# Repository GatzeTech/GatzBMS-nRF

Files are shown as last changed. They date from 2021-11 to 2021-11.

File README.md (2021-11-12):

# GatzBMS-nRF

Short explanation for now.

I was a bit annoyed with the Chinese BMS's that you don't have any feedback on the status of for example balancing or why it cutt off power. Once I was in the middle of nowhere when my eBike suddenly stopped and physically I'm really dependant on the electric system so for example in such case, I want to read out the voltage's and decide for myself if it is still safe to go on. If I have to bike myself physically longer distance's (5 km) I can be sick for day's. In that case one cell group was a little bit off, but still in the safe range, in that case I want to be able to put the mosfets on again for example via bluetooth.

So I came up with the idea to design myself a BMS. The goal is to use simple components (also with the chip delivery problems in mind) except for the microcontroller/Soc. It's a compromise between functionality, costs, availability, simplicity.

Design choice's I will discuss later.

At the moment I'm busy with the software.

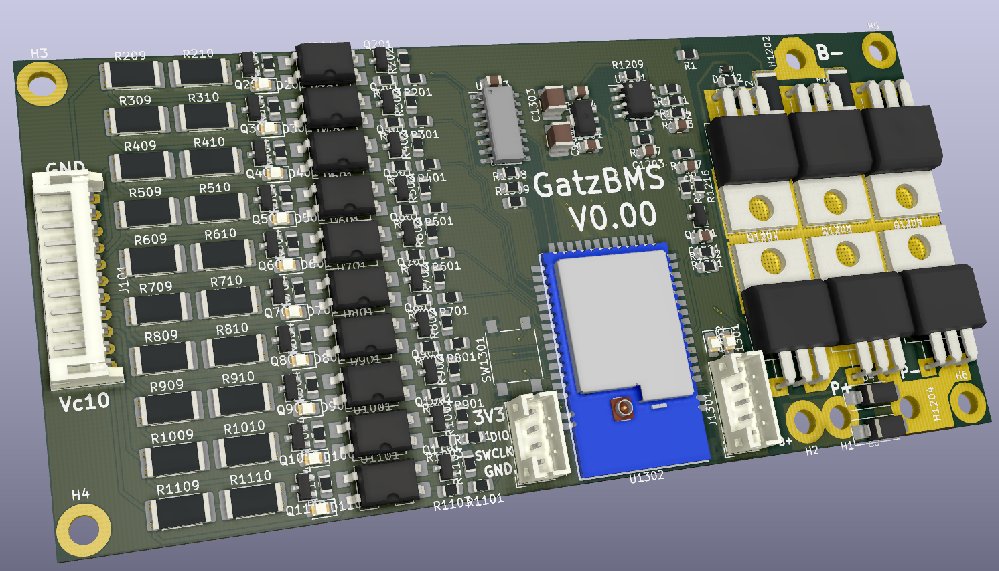
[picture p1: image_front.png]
This is an image


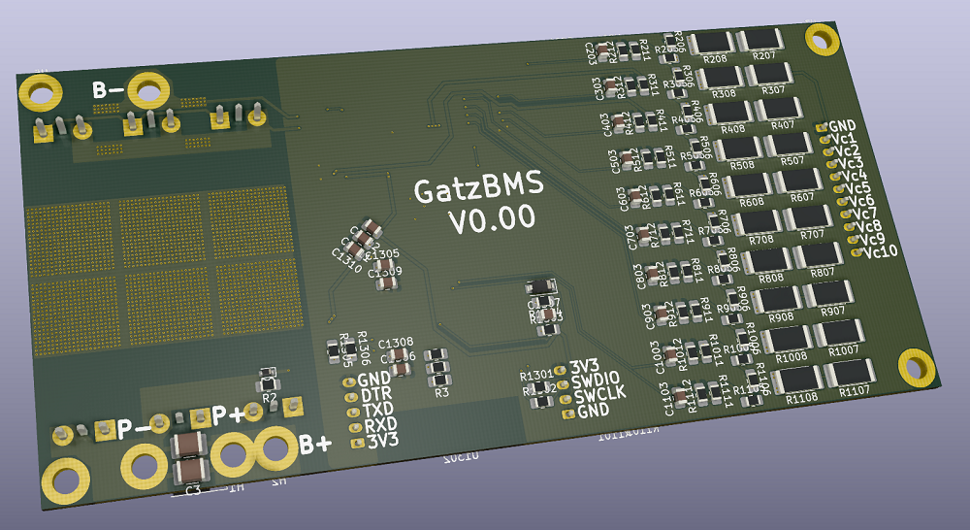
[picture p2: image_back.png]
This is an image


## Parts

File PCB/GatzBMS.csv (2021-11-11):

Reference | Quantity | Value | Footprint | Datasheet | Supplier 2 | Supplier 2 Part Number | Supplier 1 | Supplier 1 Part Number | Supplier 5 | Supplier 5 Part Number
C1 C1201 | 2 | 1N | Capacitor_SMD:C_0805_2012Metric_Pad1.18x1.45mm_HandSolder | ~
C1202 C1203 C1301 C1304 C1305 C1306 C1307 C1308 C1309 C1310 C1311 C1312 C1313 | 13 | 100N | Capacitor_SMD:C_0805_2012Metric | ~
C1302 C1303 | 2 | 4.7u | Capacitor_SMD:C_1210_3225Metric_Pad1.33x2.70mm_HandSolder | ~ | Reichelt | KEM X7R1210 4,7U
C2 C3 | 2 | 1.5u | Capacitor_SMD:C_1210_3225Metric_Pad1.33x2.70mm_HandSolder | ~ | Reichelt | ECC KTS101B155K1
C203 C303 C403 C503 C603 C703 C803 C903 C1003 C1103 | 10 | 1N | Capacitor_SMD:C_0805_2012Metric | ~
D1 | 1 | 1N4148W | Diode_SMD:D_SOD-123 | https://www.vishay.com/docs/85748/1n4148w.pdf |  |  | Conrad | 1582022
D2 D1202 | 2 | Z1SMA15 | Diode_SMD:D_SOD-523 |  |  |  | Conrad | 556861
D1302 | 1 | Red | LED_SMD:LED_0805_2012Metric_Pad1.15x1.40mm_HandSolder | ~ | Reichelt | RND 135-00184
D201 D301 D401 D501 D601 D701 D801 D901 D1001 D1101 D1301 | 11 | Green | LED_SMD:LED_0805_2012Metric_Pad1.15x1.40mm_HandSolder | ~ | Reichelt | OSO LGR971
D3 D4 | 2 | D | Diode_SMD:D_SMA_Handsoldering | ~ | Reichelt | M2 DIO
H1 H2 H3 H4 H5 H6 H1202 H1204 | 8 | MountingHole_Pad | MountingHole:MountingHole_3.2mm_M3_ISO7380_Pad_TopBottom | ~
J101 | 1 | Conn_01x11 | Connector_JST:JST_PH_S11B-PH-K_1x11_P2.00mm_Horizontal | ~
J1301 | 1 | Conn_01x05 | Connector_JST:JST_PH_B5B-PH-K_1x05_P2.00mm_Vertical | ~ |  |  | Conrad | 741246
J1302 | 1 | Conn_01x04 | Connector_JST:JST_PH_B4B-PH-K_1x04_P2.00mm_Vertical | ~ |  |  | Conrad | 741223
Q1204 Q1205 Q1206 Q1207 Q1208 Q1209 | 6 | IRFB4410ZPBF | GatzeLib:TO-220-3_Horizontal_TabDown_modified |  |  |  | Conrad | 160946
Q201 Q301 Q401 Q501 Q601 Q701 Q801 Q901 Q1001 Q1101 Q1201 | 11 | BC847 | Package_TO_SOT_SMD:SOT-23 | http://www.infineon.com/dgdl/Infineon-BC847SERIES_BC848SERIES_BC849SERIES_BC850SERIES-DS-v01_01-en.pdf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 |  |  | Conrad | 153157
Q202 Q302 Q402 Q502 Q602 Q702 Q802 Q902 Q1002 Q1102 | 10 | IRLML6244TRPBF | Package_TO_SOT_SMD:SOT-23 |  |  |  | Conrad | 161189
R1 R1307 R1308 R1309 | 4 | 330 | Resistor_SMD:R_0805_2012Metric_Pad1.20x1.40mm_HandSolder | ~
R1201 R1209 R1211 R1303 | 4 | 10K | Resistor_SMD:R_0805_2012Metric_Pad1.20x1.40mm_HandSolder | ~
R1205 R1207 R1208 | 3 | 100K | Resistor_SMD:R_0805_2012Metric_Pad1.20x1.40mm_HandSolder | ~
R1212 R1213 | 2 | 0.005 | Resistor_SMD:R_2512_6332Metric_Pad1.40x3.35mm_HandSolder | ~ |  |  | Conrad | 454322
R3 R4 R5 R1216 R1301 R1302 R1304 | 7 | 100 | Resistor_SMD:R_0805_2012Metric_Pad1.20x1.40mm_HandSolder | ~
R2 R1217 R1218 | 3 | 1M | Resistor_SMD:R_0805_2012Metric_Pad1.20x1.40mm_HandSolder | ~
R202 R302 R402 R502 R602 R702 R802 R902 R1002 R1102 | 10 | 22K | Resistor_SMD:R_0805_2012Metric_Pad1.20x1.40mm_HandSolder | ~
R203 R303 R403 R503 R603 R703 R803 R903 R1003 R1103 | 10 | 620 | Resistor_SMD:R_0805_2012Metric_Pad1.20x1.40mm_HandSolder | ~
R201 R204 R205 R301 R304 R305 R401 R404 R405 R501 R504 R505 R601 R604 R605 R701 R704 R705 R801 R804 R805 R901 R904 R905 R1001 R1004 R1005 R1101 R1104 R1105 R1203 R1204 R1305 R1306 | 34 | 1K | Resistor_SMD:R_0805_2012Metric_Pad1.20x1.40mm_HandSolder | ~
R206 R306 R406 R506 R606 R706 R806 R906 R1006 R1106 R1202 | 11 | 47K | Resistor_SMD:R_0805_2012Metric_Pad1.20x1.40mm_HandSolder | ~
R207 R208 R209 R210 R307 R308 R309 R310 R407 R408 R409 R410 R507 R508 R509 R510 R607 R608 R609 R610 R707 R708 R709 R710 R807 R808 R809 R810 R907 R908 R909 R910 R1007 R1008 R1009 R1010 R1107 R1108 R1109 R1110 | 40 | 10 | Resistor_SMD:R_2512_6332Metric_Pad1.40x3.35mm_HandSolder | ~ |  |  | Conrad | 443148
R211 R311 R411 R511 R611 R711 R811 R911 R1011 R1111 | 10 | 91K | Resistor_SMD:R_0805_2012Metric_Pad1.20x1.40mm_HandSolder | ~
R212 R312 R412 R512 R612 R712 R812 R912 R1012 R1112 | 10 | 6K8 | Resistor_SMD:R_0805_2012Metric_Pad1.20x1.40mm_HandSolder | ~
SW1301 | 1 | SW_Push | Button_Switch_SMD:SW_Push_1P1T_NO_6x6mm_H9.5mm | ~ |  |  |  |  | Aliexpress | 1005001861089000
U1201 | 1 | MCP607 | Package_SO:SOIC-8_3.9x4.9mm_P1.27mm |  | Reichelt | MCP 607-I/SN
U1301 | 1 | MCP1703A-1202_SOT89 | Package_TO_SOT_SMD:SOT-89-3 | http://ww1.microchip.com/downloads/en/DeviceDoc/20005122B.pdf | Reichelt | MCP 1703-3302MB
U1302 | 1 | E73-2G4M04S1B | GatzeLib:E73-2G4M04S1B | http://infocenter.nordicsemi.com/pdf/nRF52832_PS_v1.4.pdf
U1303 | 1 | 74HC4051 | Package_SO:SO-16_3.9x9.9mm_P1.27mm | http://www.ti.com/lit/ds/symlink/cd74hc4051.pdf |  |  | Conrad | 144444
U201 U301 U401 U501 U601 U701 U801 U901 U1001 U1101 | 10 | PC817 | Package_DIP:SMDIP-4_W9.53mm_Clearance8mm | http://www.soselectronic.cz/a_info/resource/d/pc817.pdf |  |  | Conrad | 140234

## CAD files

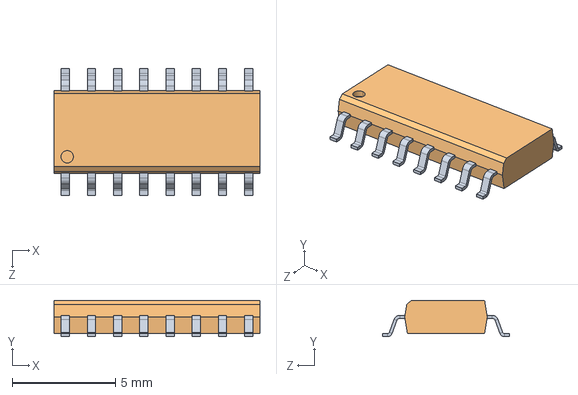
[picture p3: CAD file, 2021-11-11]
PCB/3dshape/SO16.STEP
9.97 x 1.76 x 6.14 mm

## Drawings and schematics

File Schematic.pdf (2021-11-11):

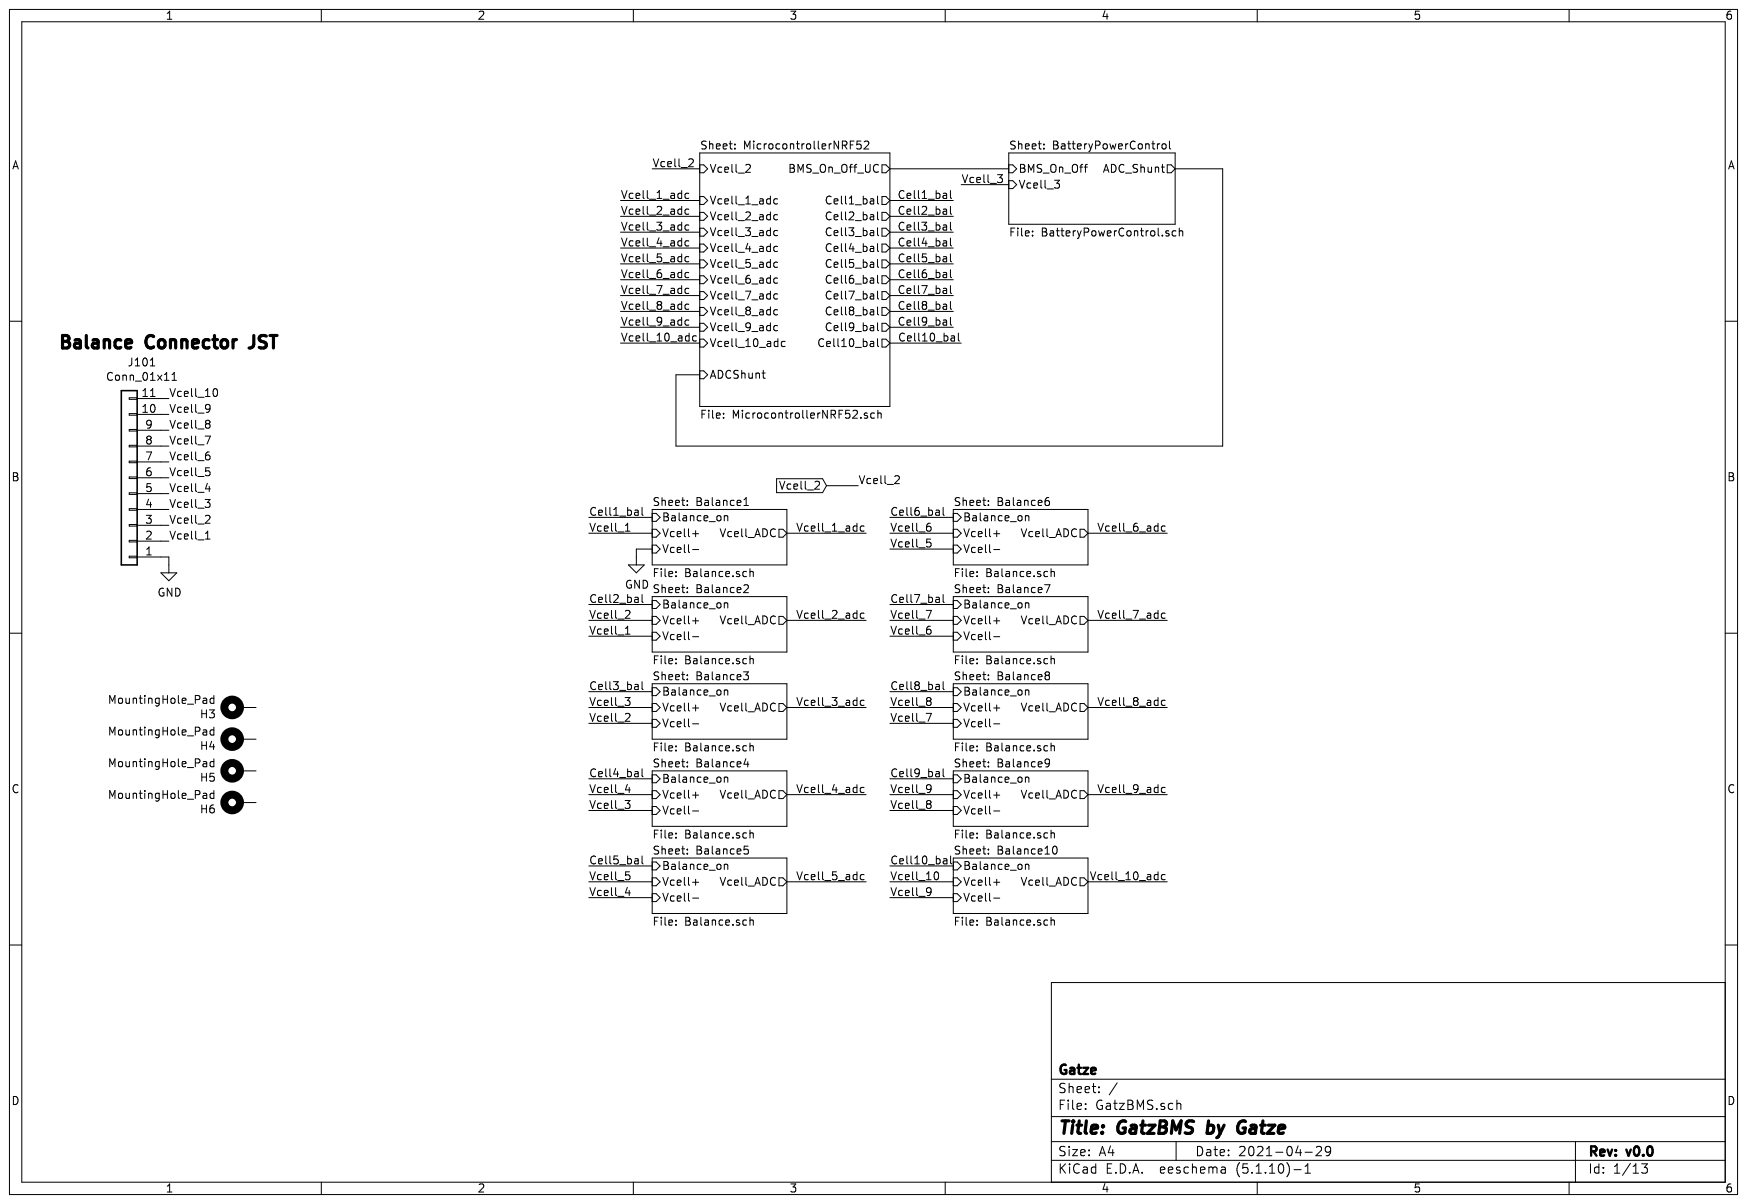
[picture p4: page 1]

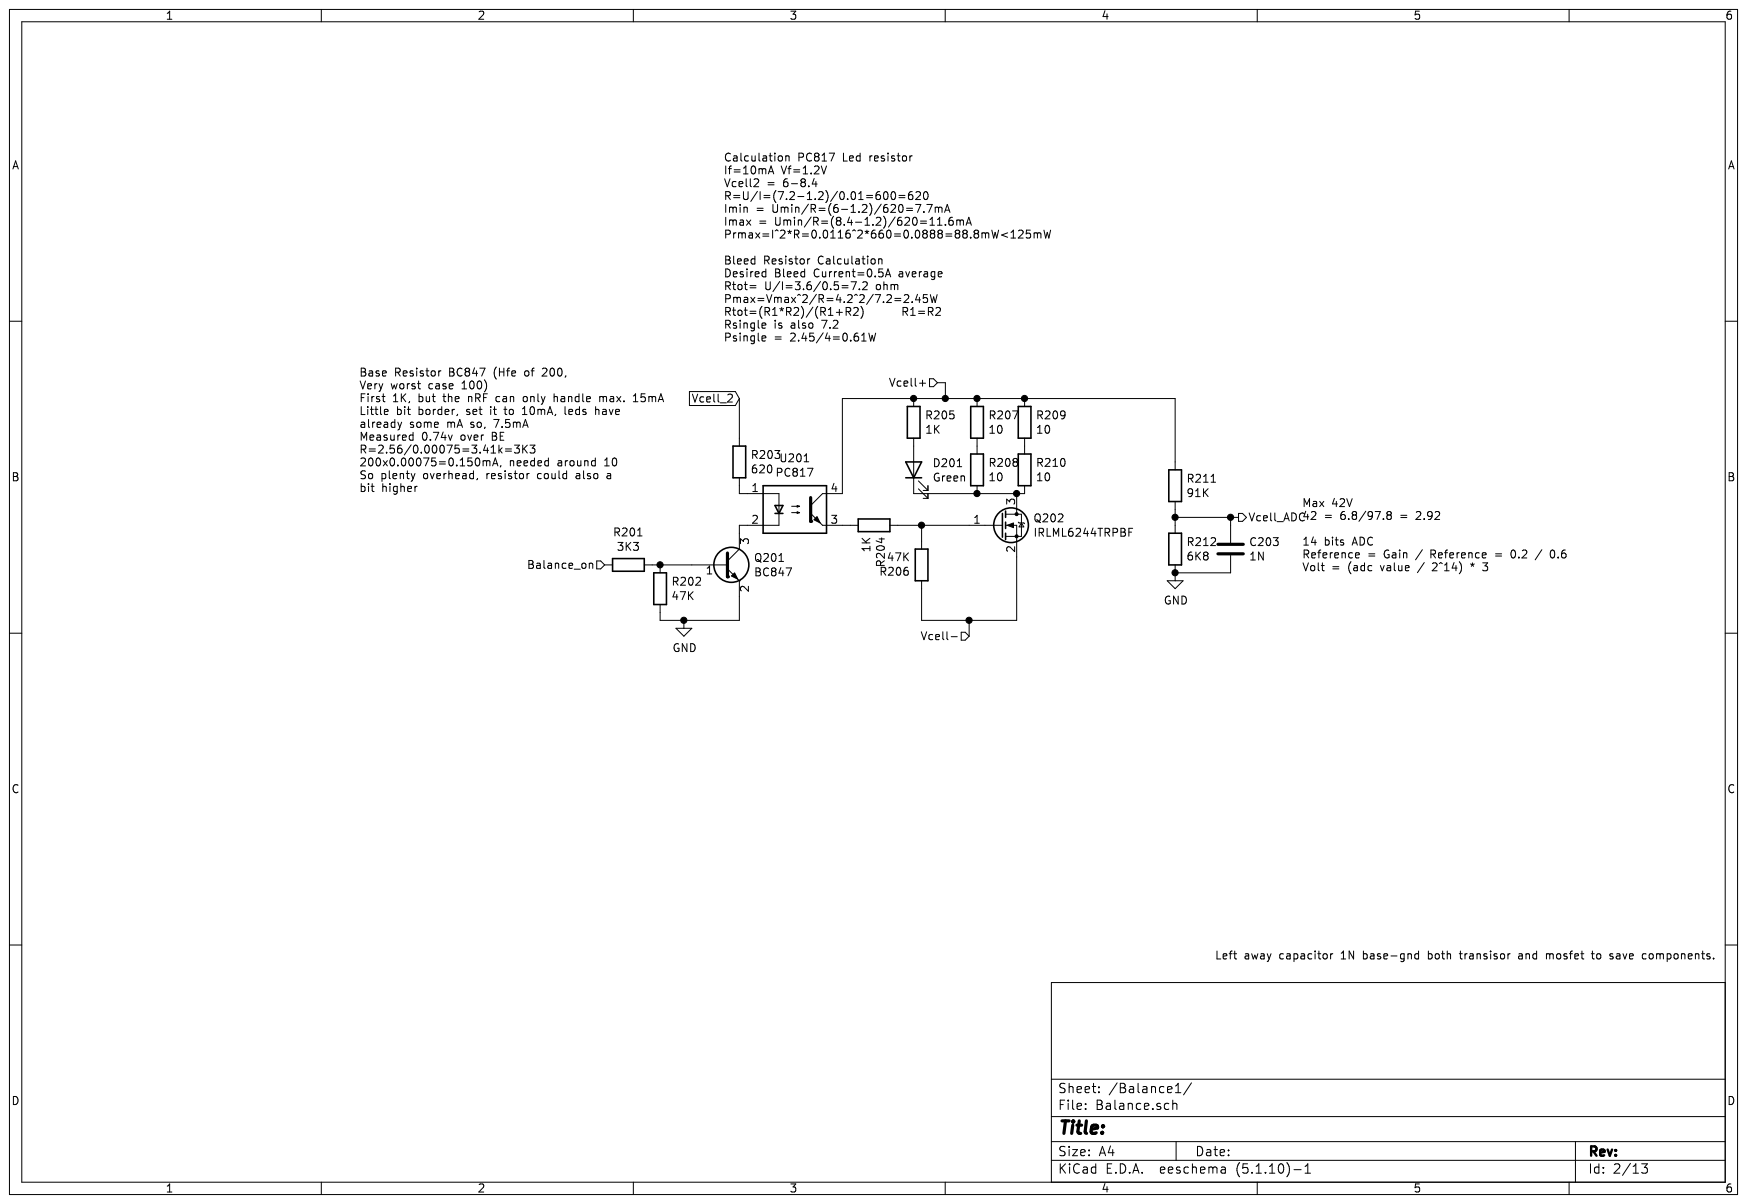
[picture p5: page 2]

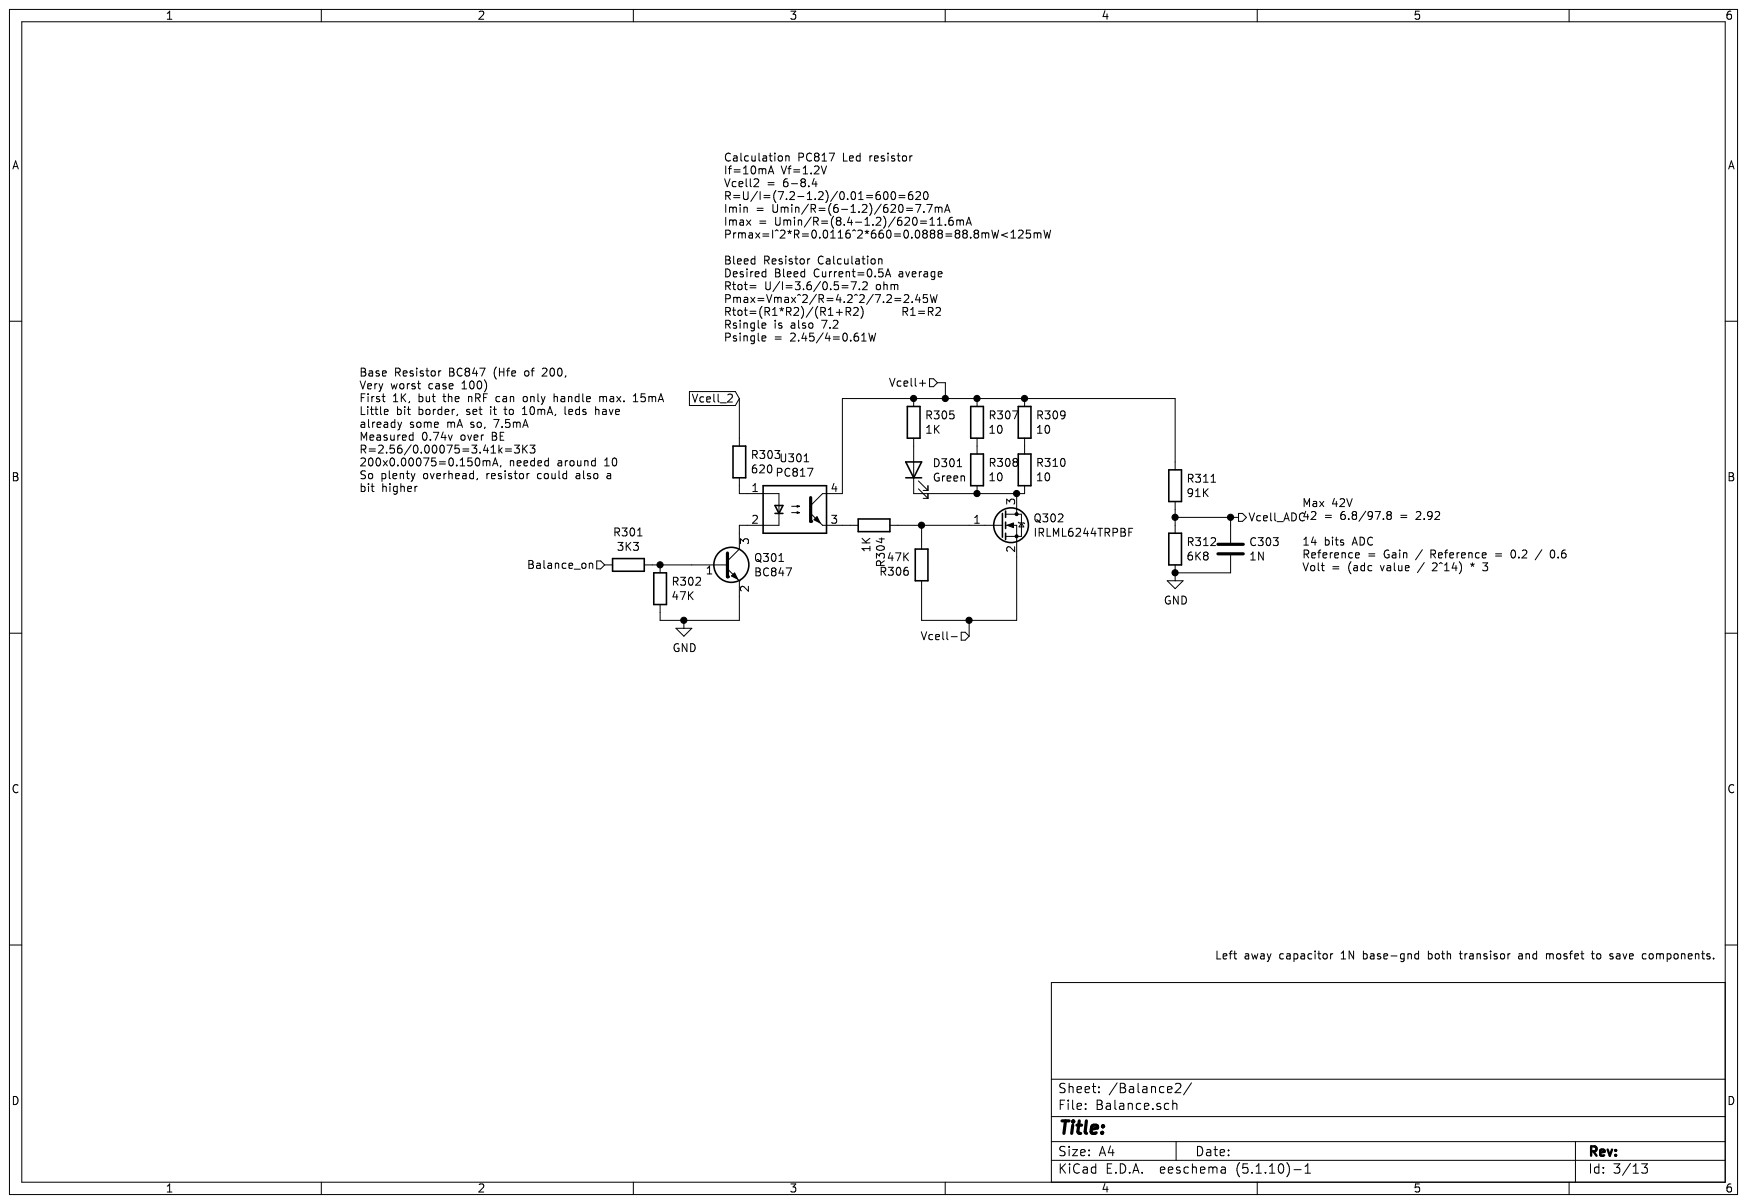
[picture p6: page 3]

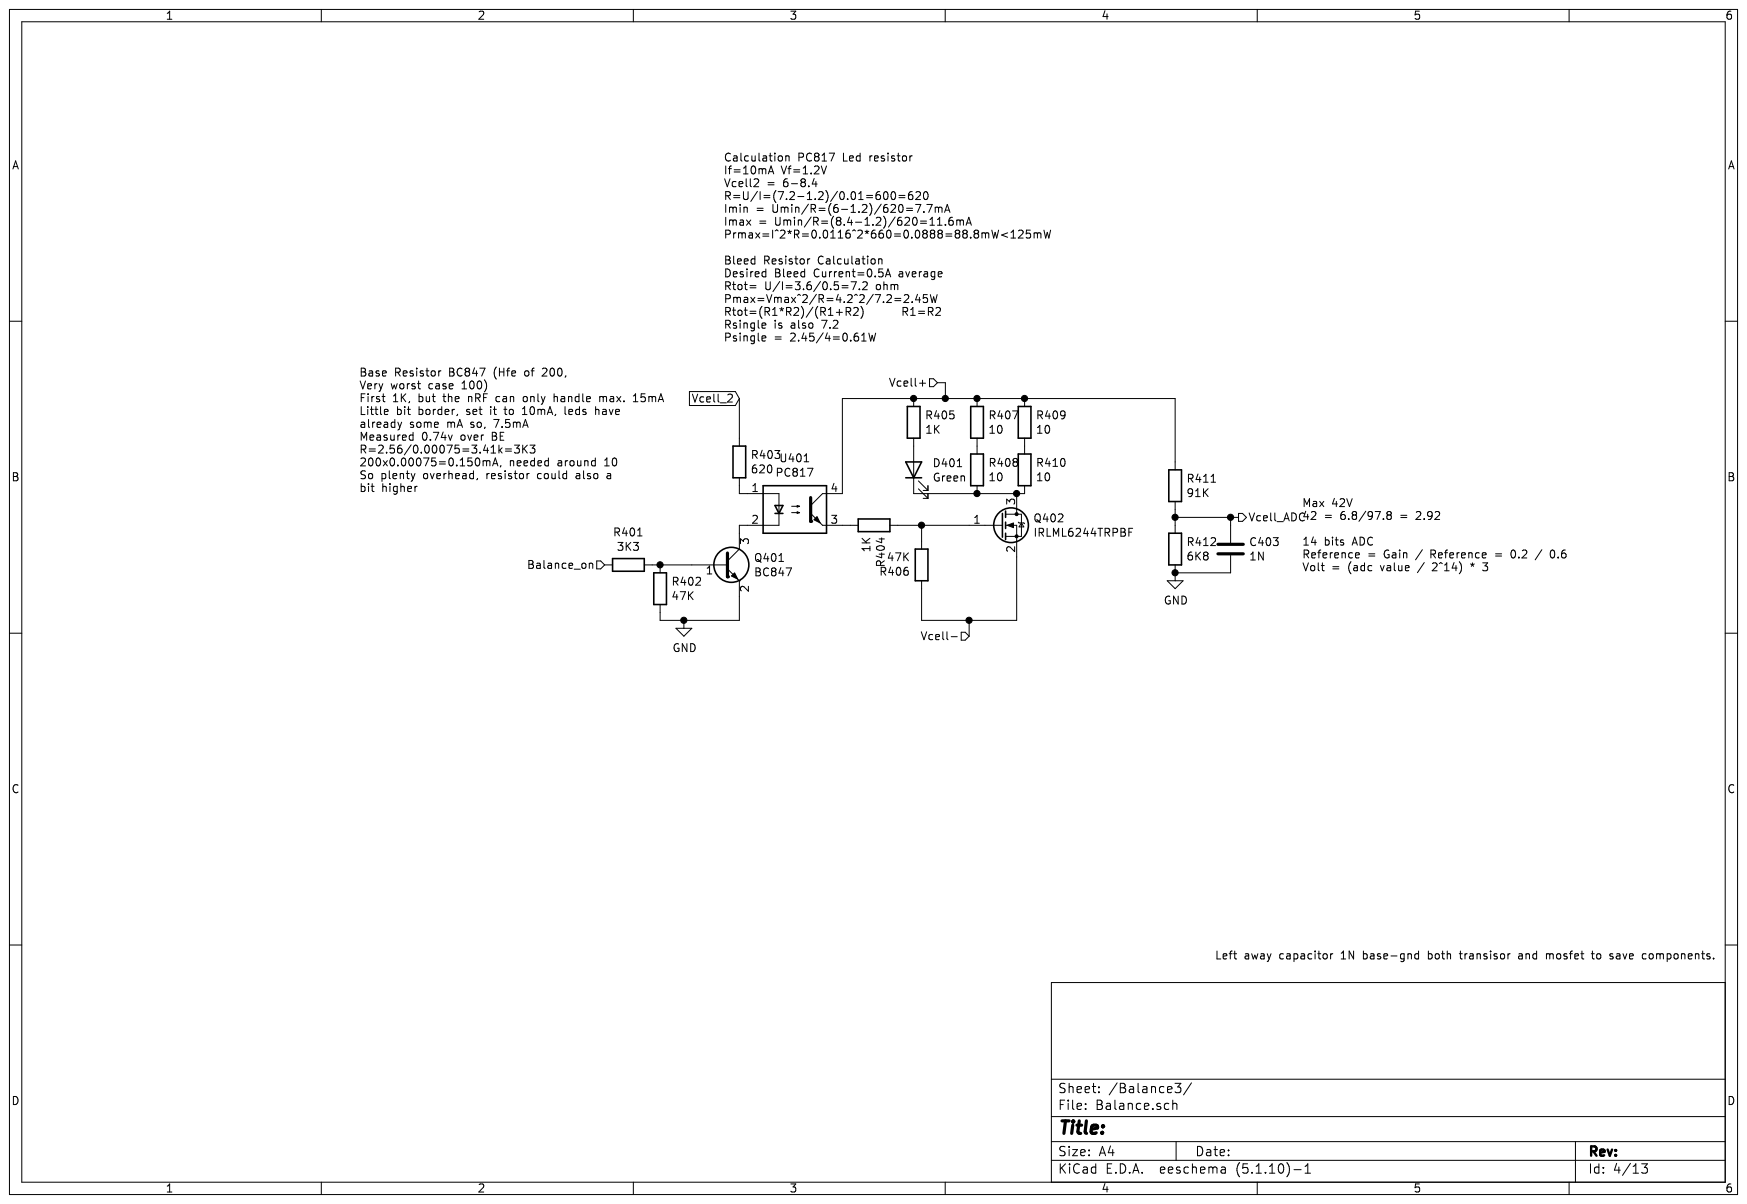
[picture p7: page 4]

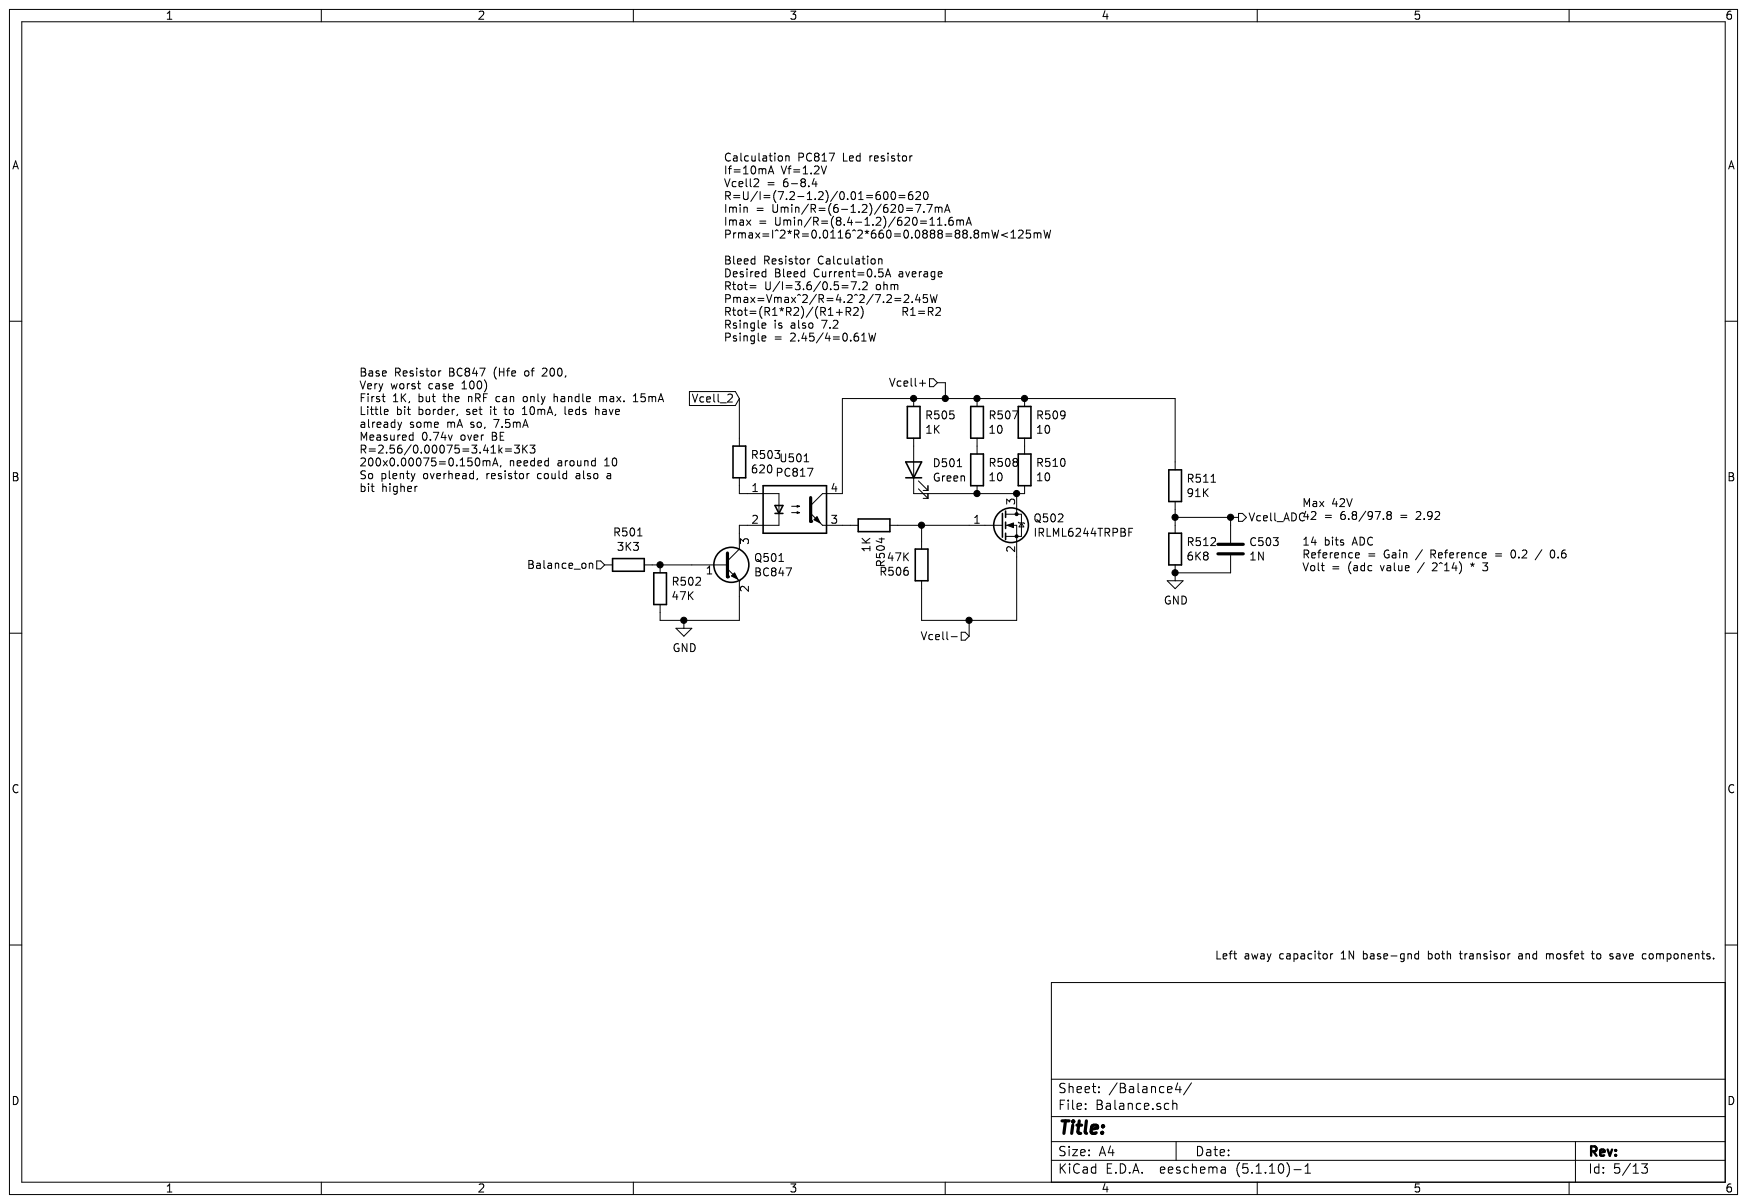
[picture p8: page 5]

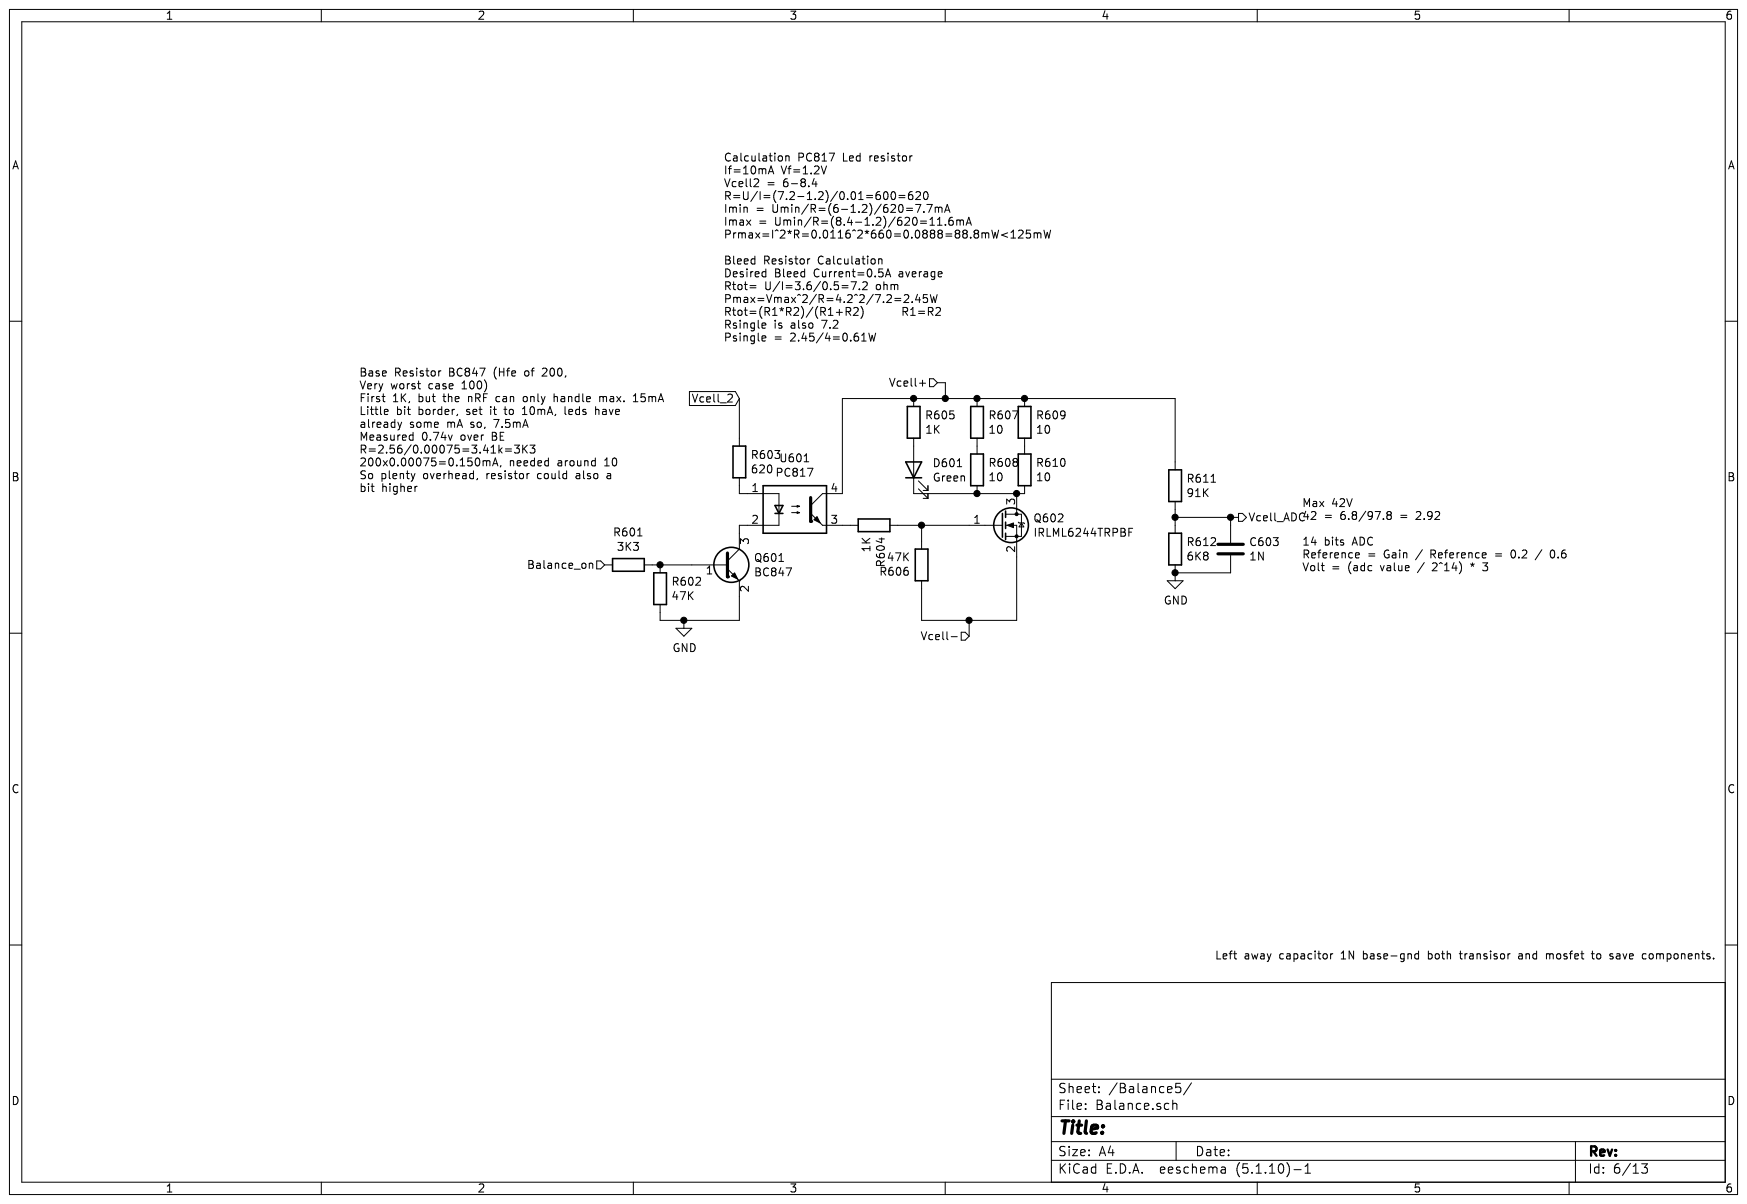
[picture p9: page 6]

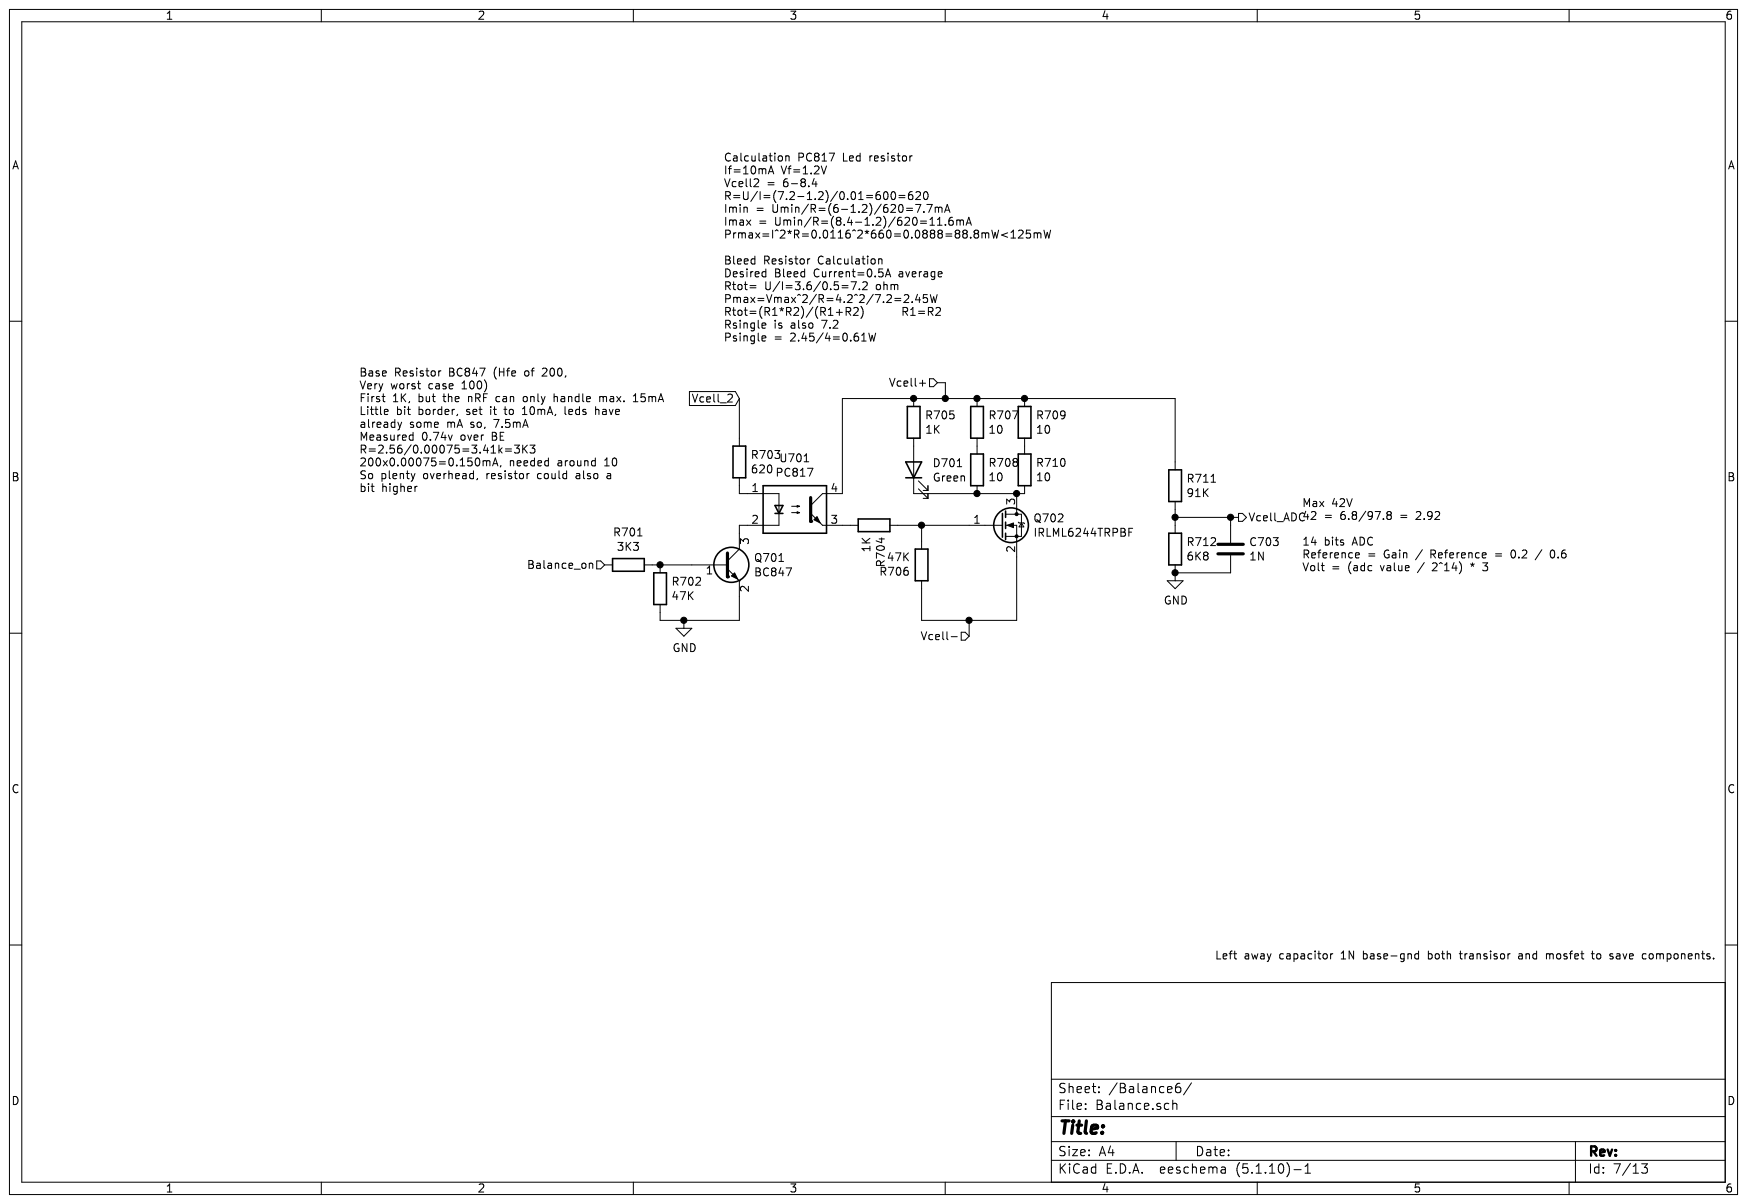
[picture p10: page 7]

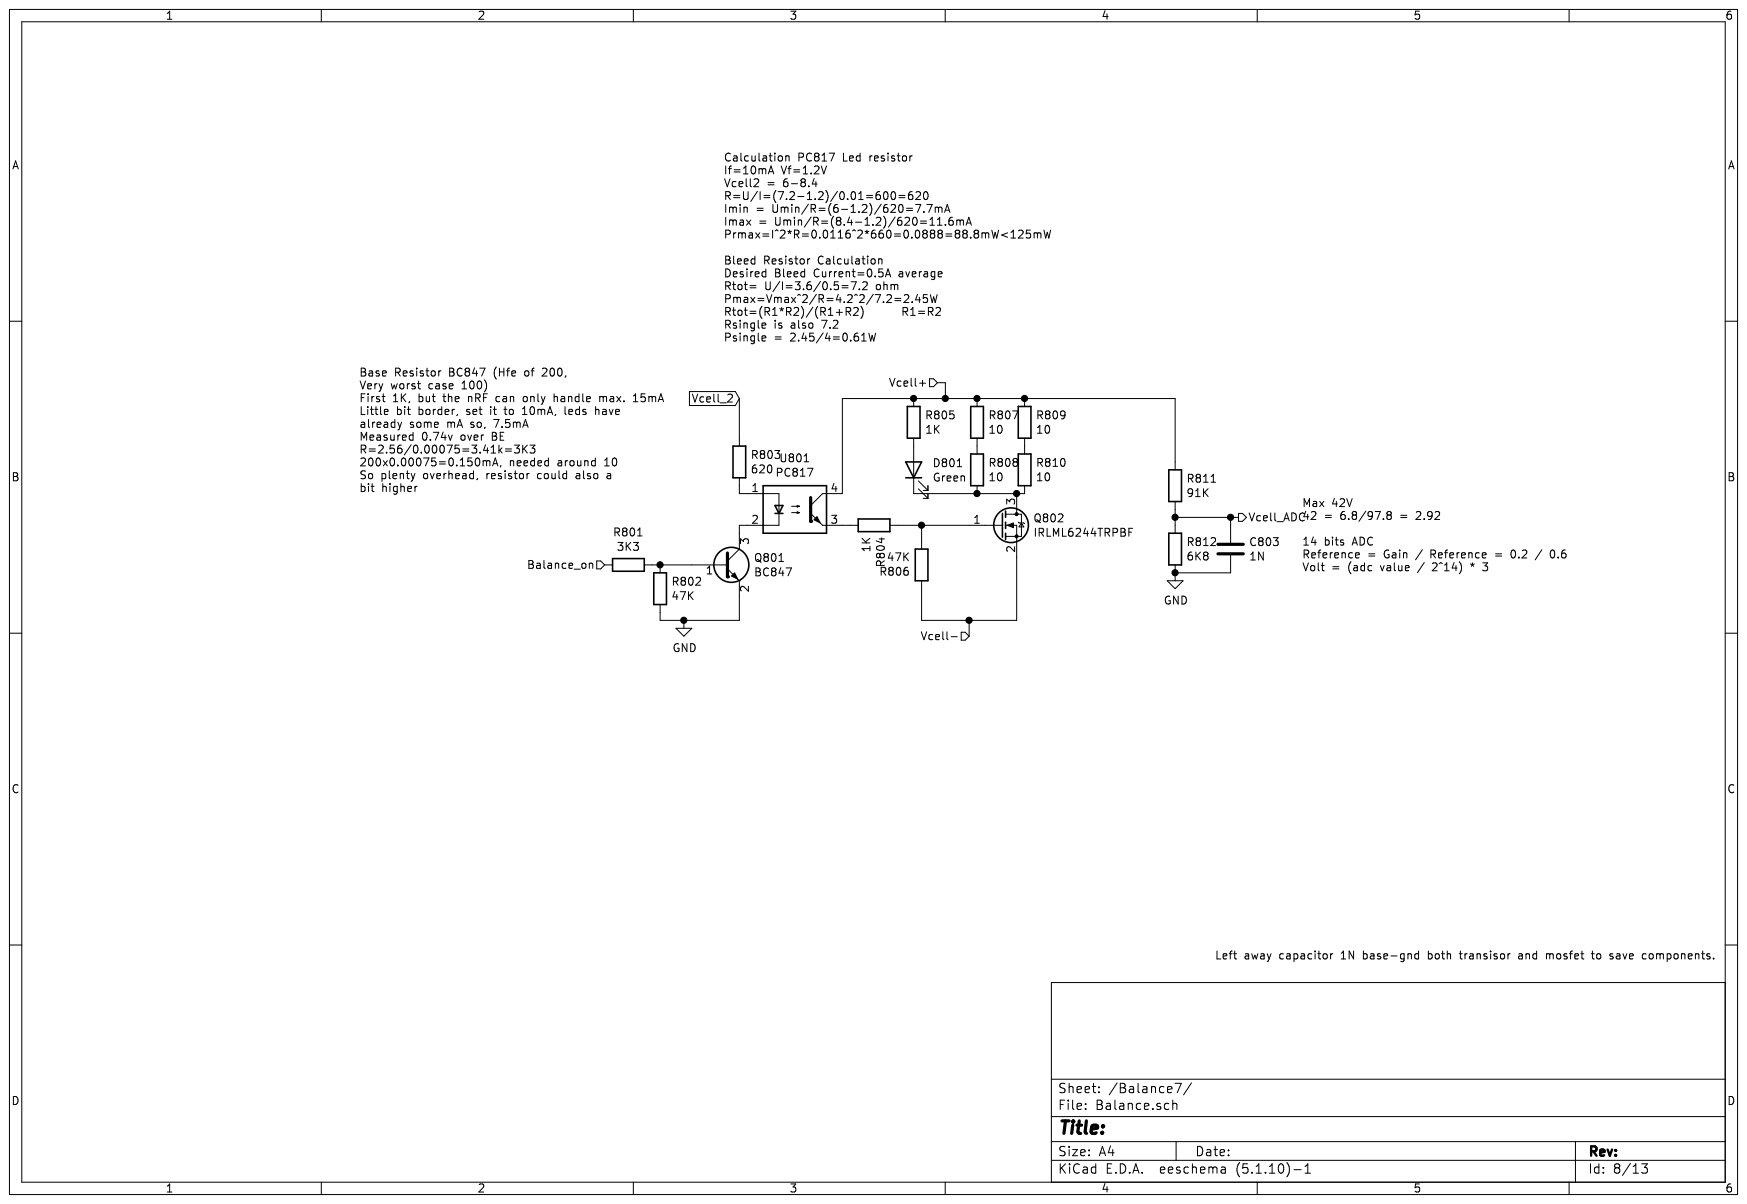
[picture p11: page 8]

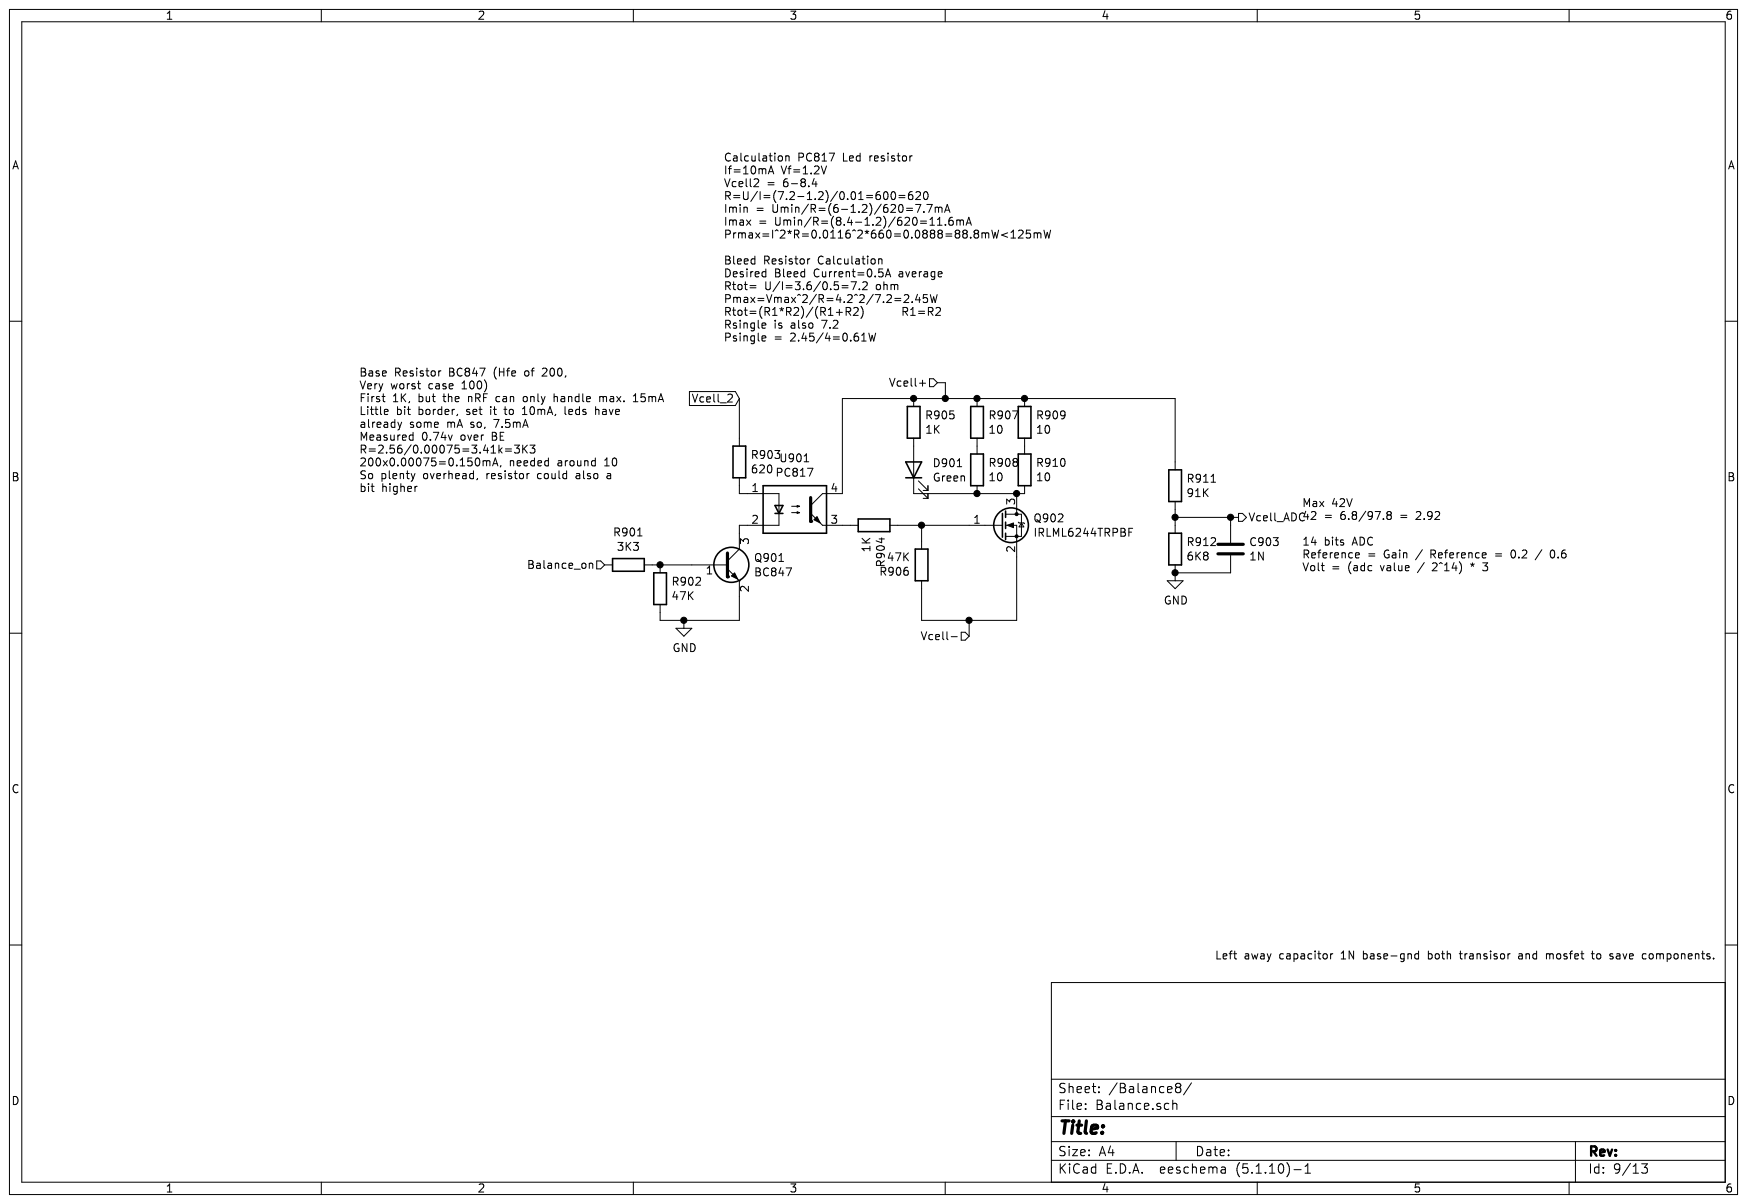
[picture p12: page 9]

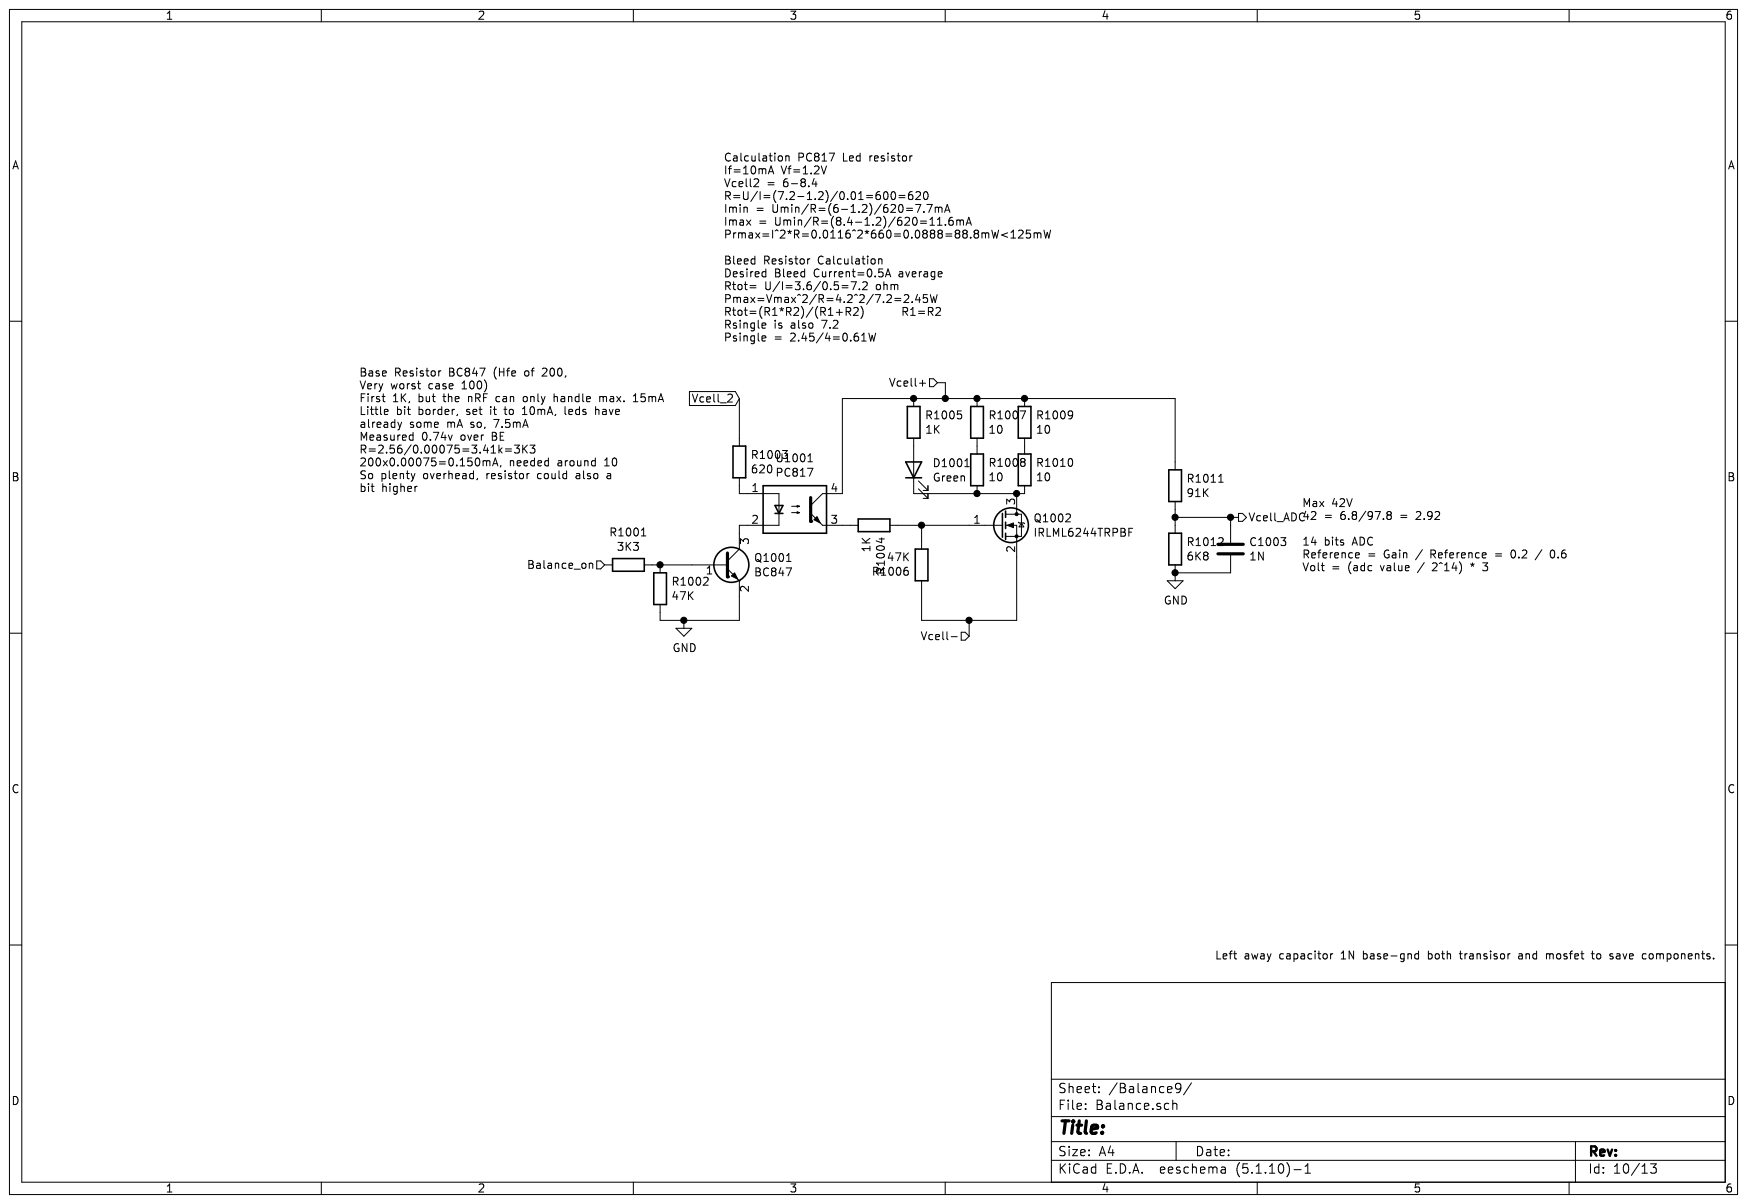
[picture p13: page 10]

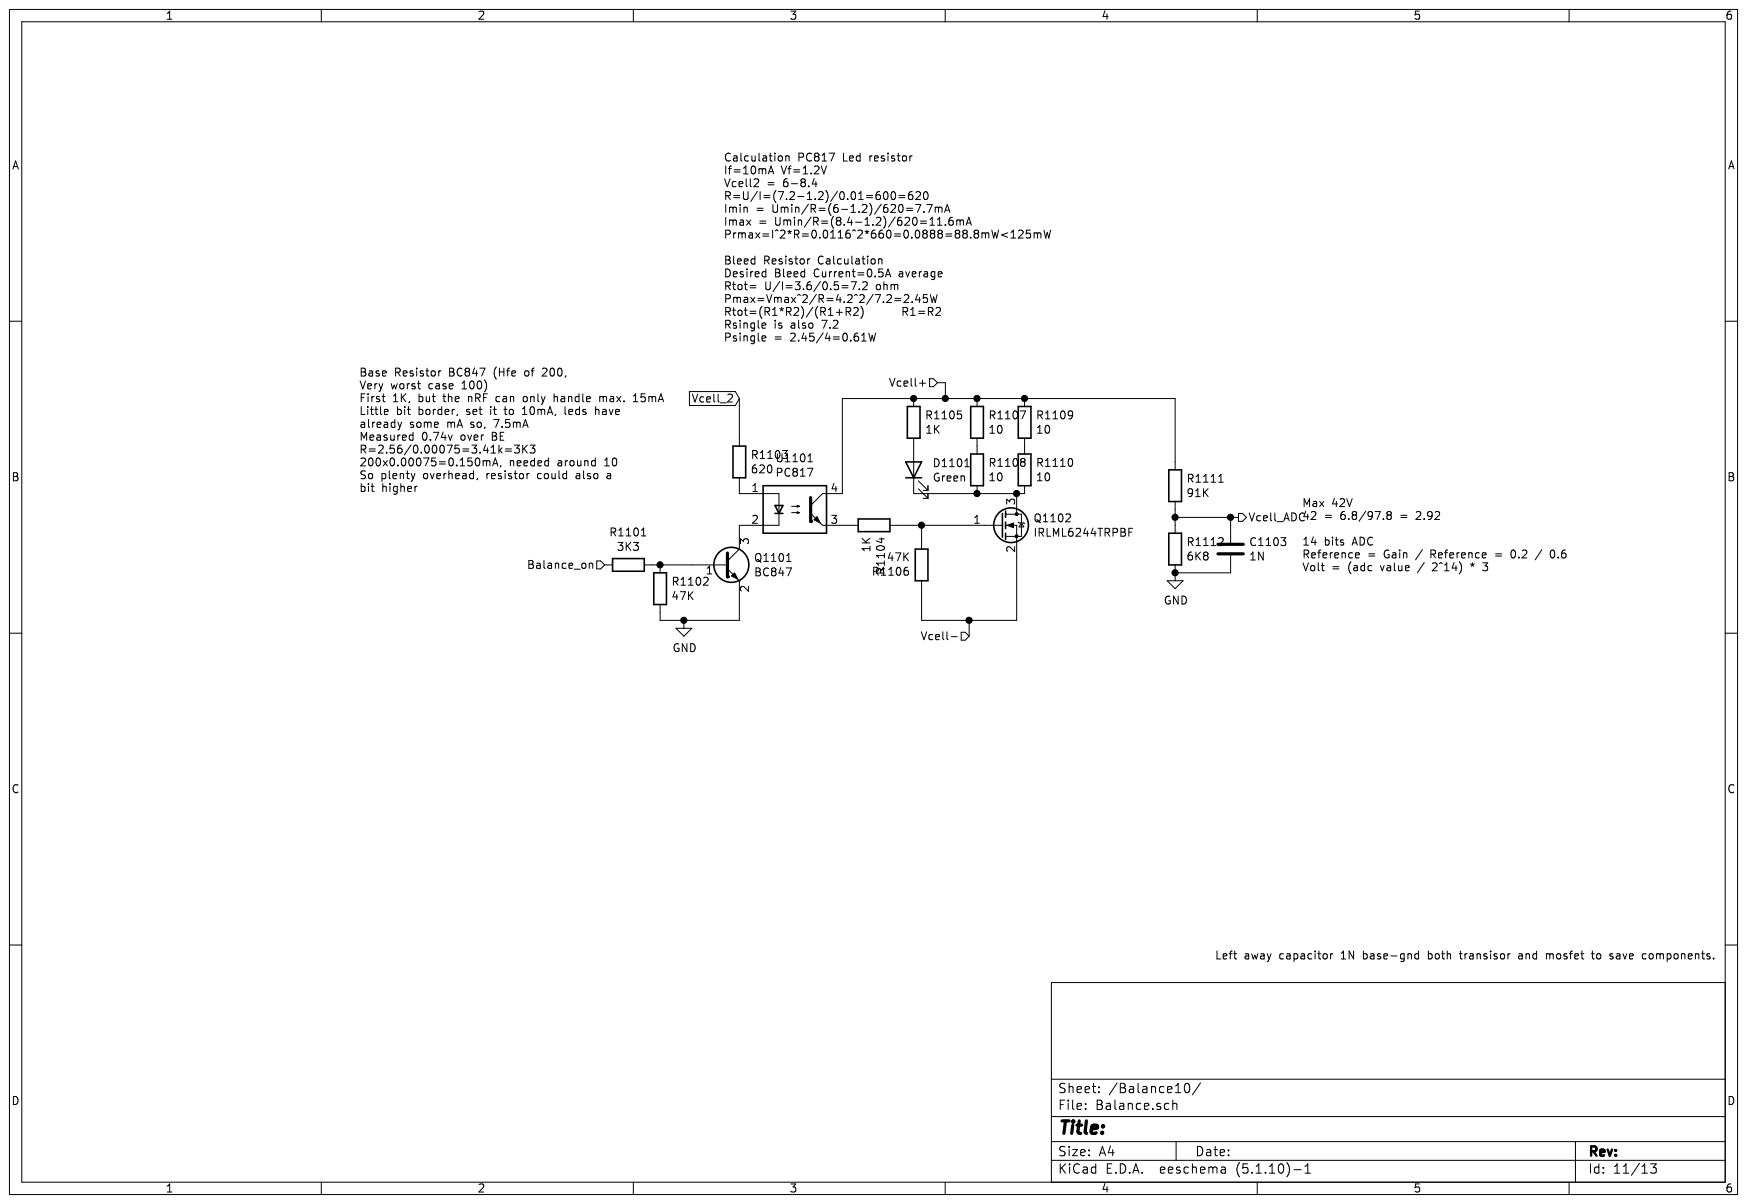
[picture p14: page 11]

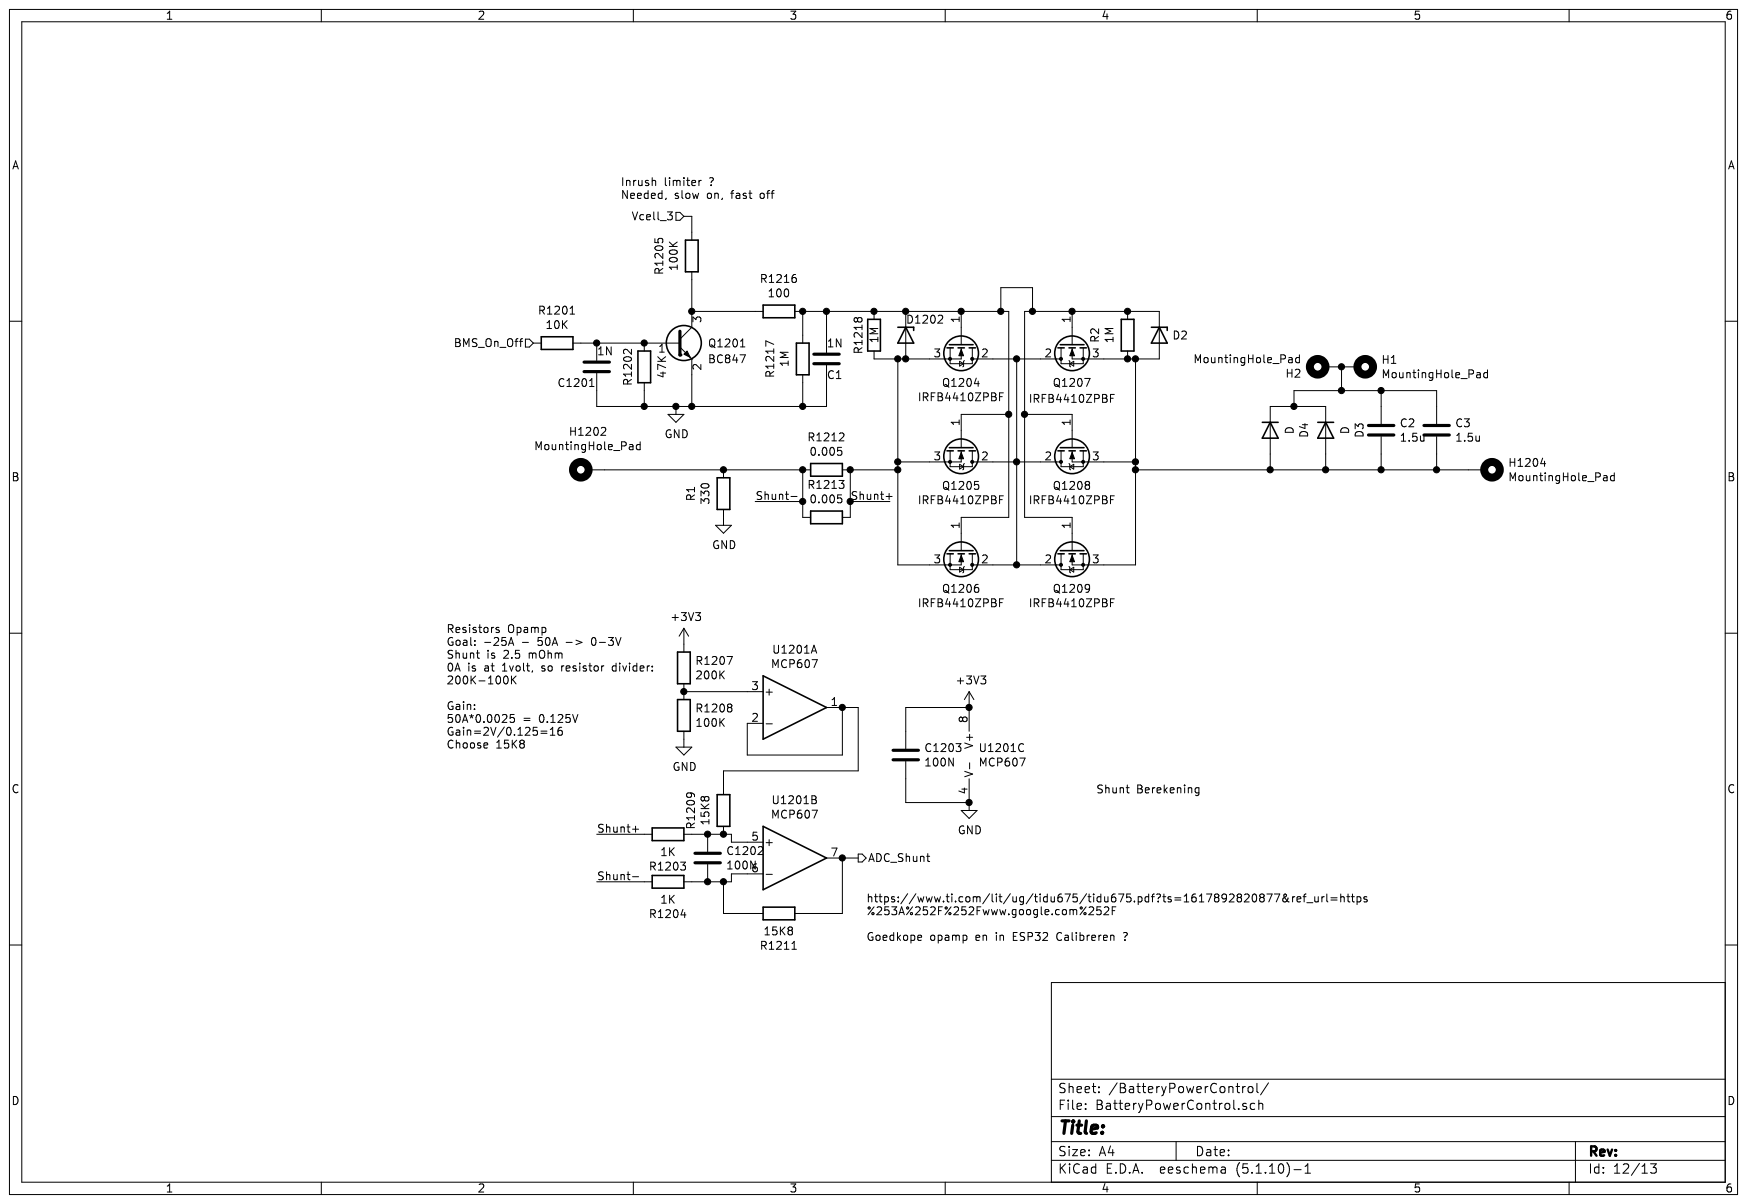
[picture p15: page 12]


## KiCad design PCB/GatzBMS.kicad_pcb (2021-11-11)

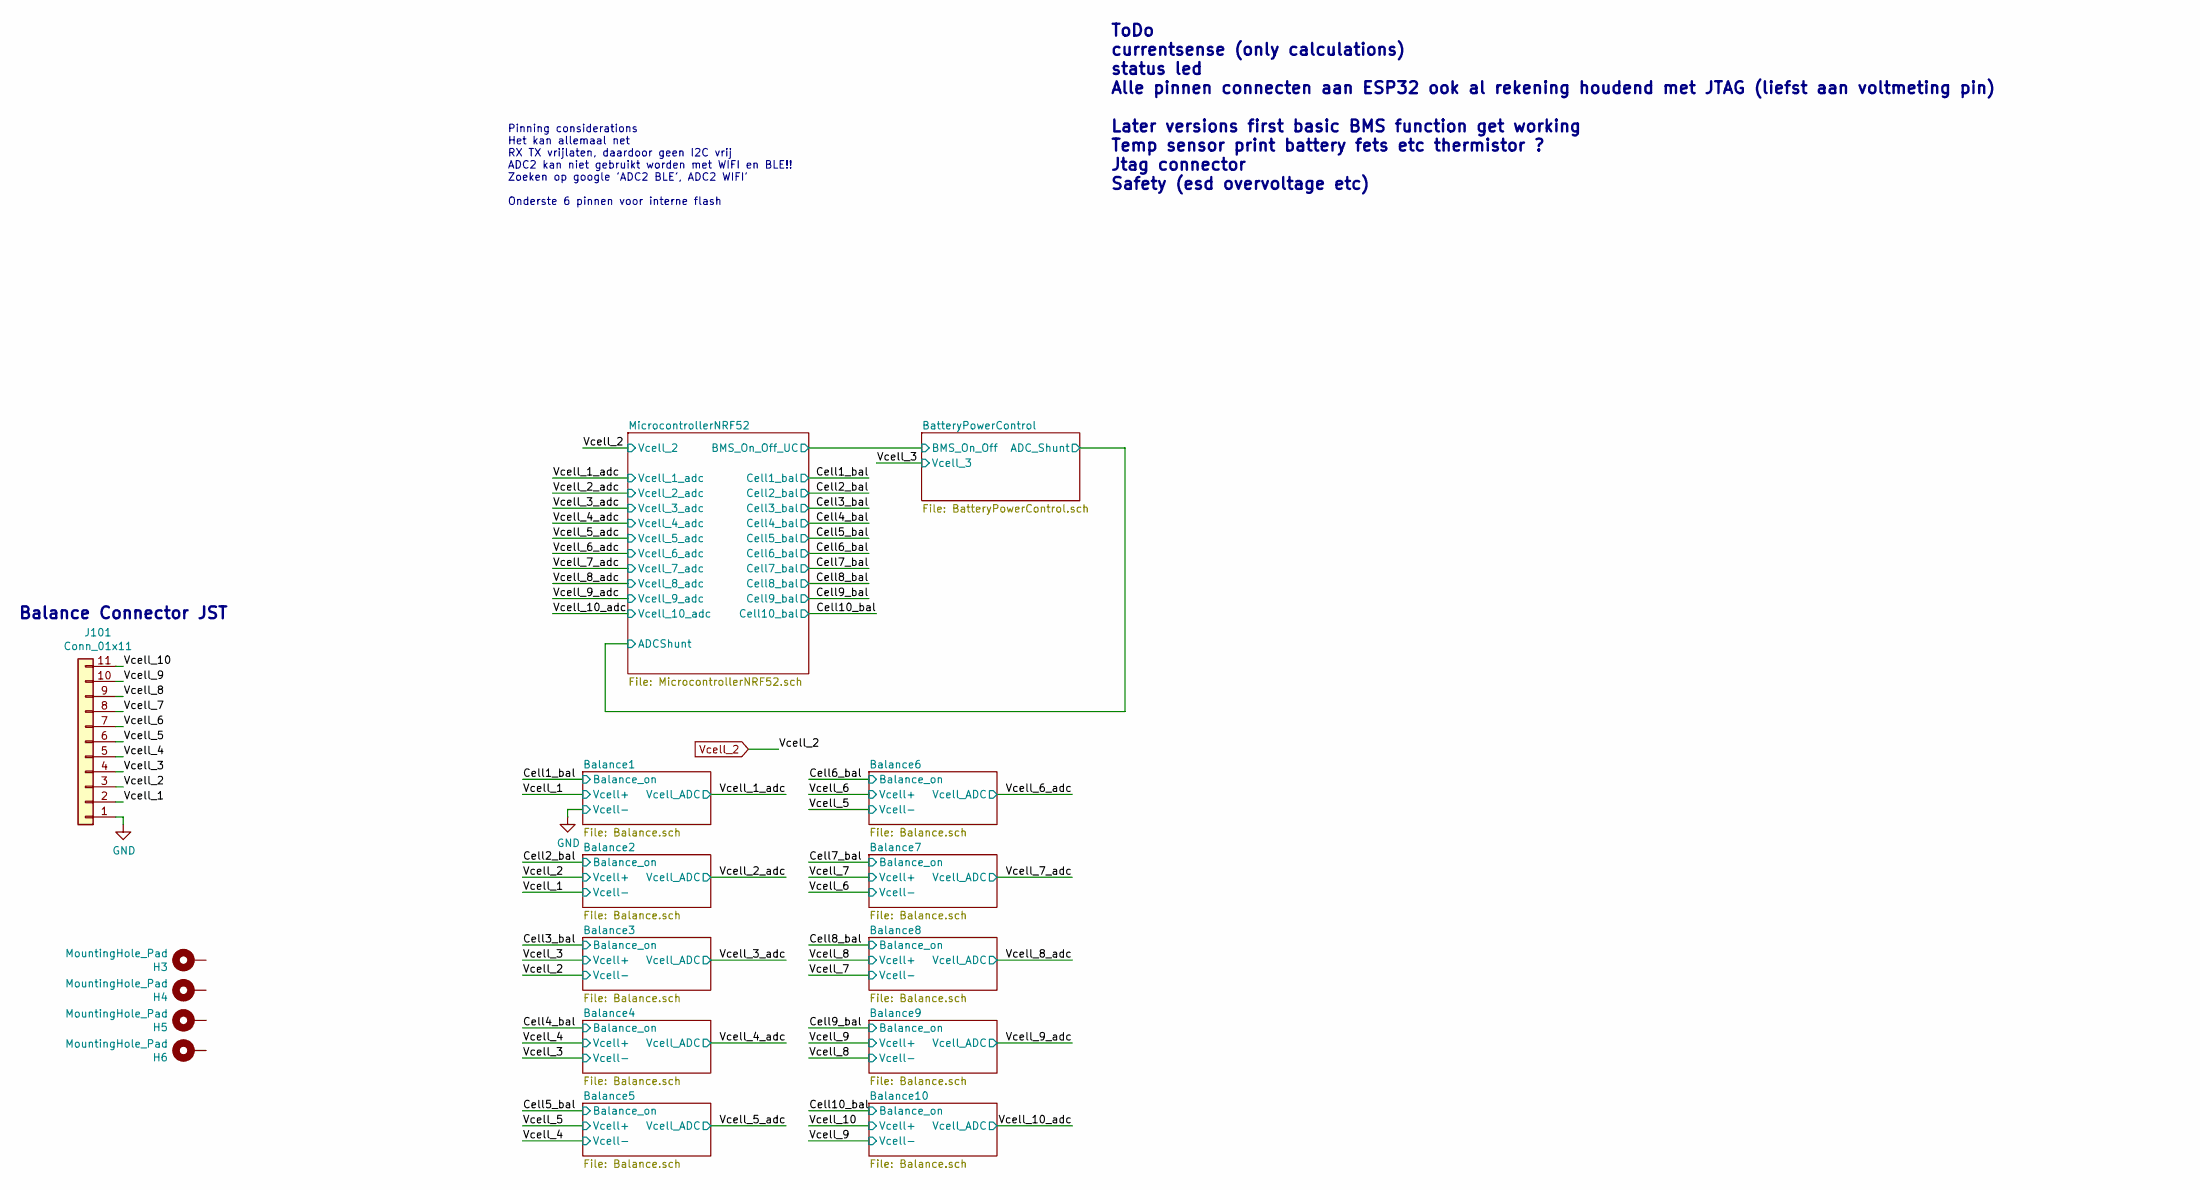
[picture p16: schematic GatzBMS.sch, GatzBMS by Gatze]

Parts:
H3, H4, H5, H6: MountingHole_Pad; MountingHole_3.2mm_M3_ISO7380_Pad_TopBottom
J101: Conn_01x11; JST_PH_S11B-PH-K_1x11_P2.00mm_Horizontal

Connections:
/Vcell_1: J101.2; also elsewhere on the board
/Vcell_3: J101.4; also elsewhere on the board
/Vcell_4: J101.5; also elsewhere on the board
/Vcell_5: J101.6; also elsewhere on the board
/Vcell_6: J101.7; also elsewhere on the board
/Vcell_7: J101.8; also elsewhere on the board
/Vcell_8: J101.9; also elsewhere on the board
/Vcell_9: J101.10; also elsewhere on the board
/Vcell_10: J101.11; also elsewhere on the board
GND: J101.1; also elsewhere on the board
Vcell_2: J101.3; also elsewhere on the board

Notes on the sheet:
Balance Connector JST
ToDo currentsense (only calculations) status led Alle pinnen connecten aan ESP32 ook al rekening houdend met JTAG (liefst aan voltmeting pin) Later versions first basic BMS function get working Temp sensor print battery fets etc thermistor ? Jtag connector Safety (esd overvoltage etc)
Pinning considerations Het kan allemaal net RX TX vrijlaten, daardoor geen I2C vrij ADC2 kan niet gebruikt worden met WIFI en BLE!! Zoeken op google 'ADC2 BLE', ADC2 WIFI' Onderste 6 pinnen voor interne flash

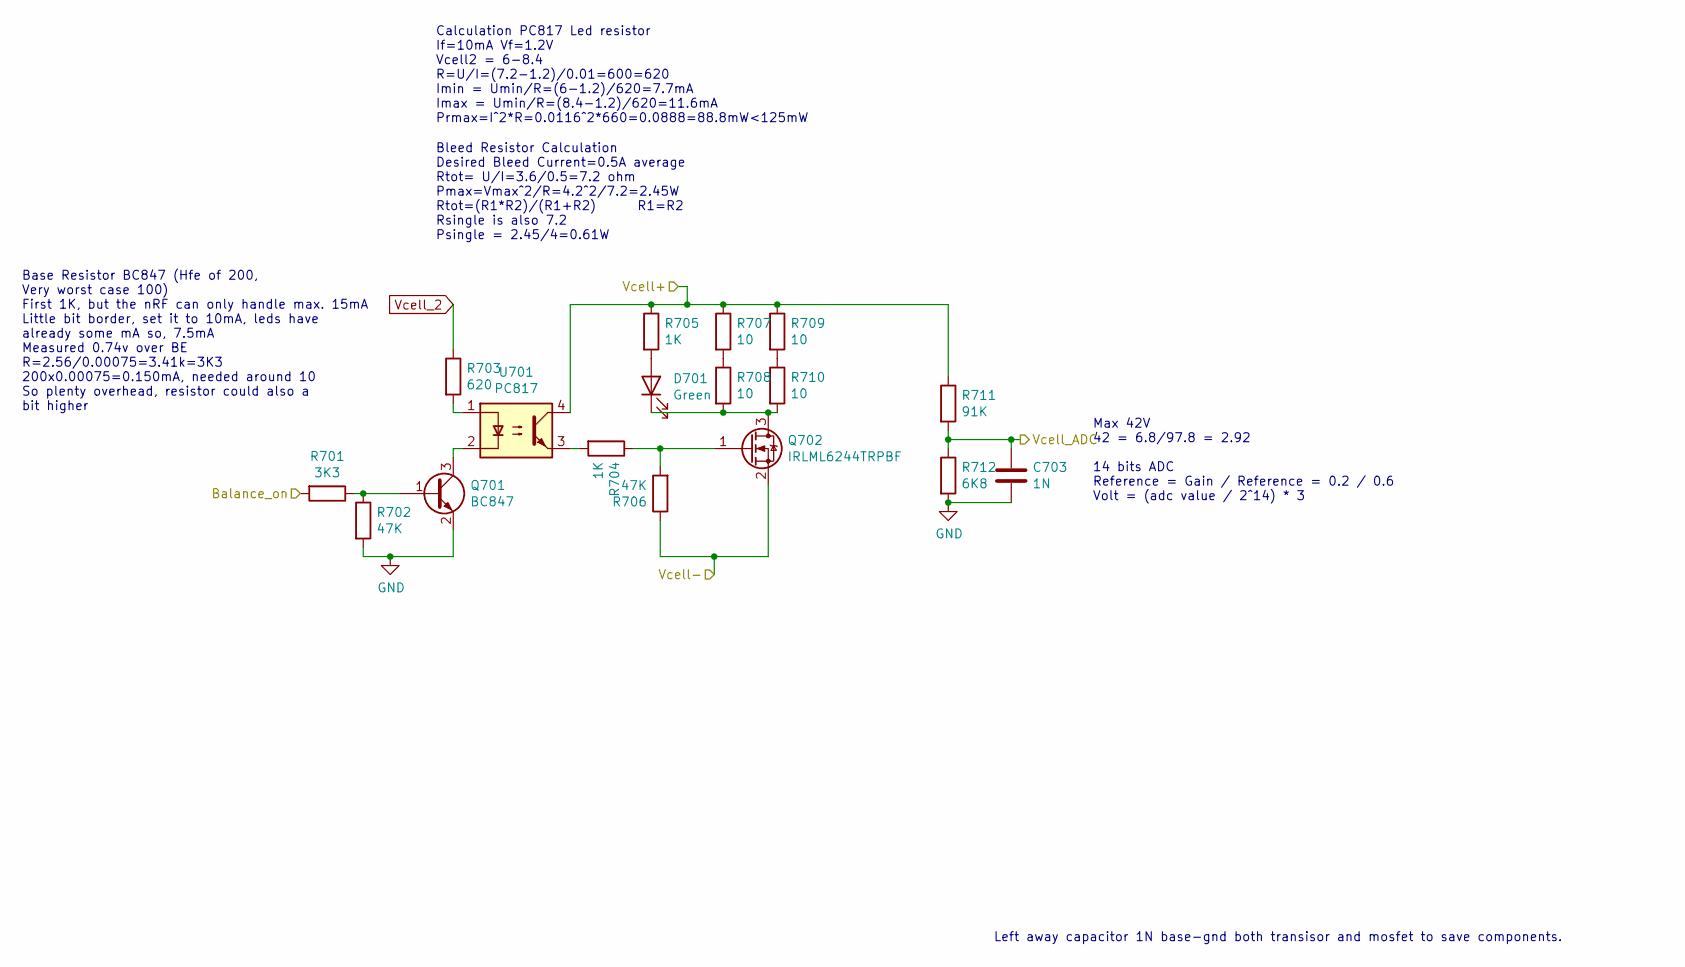
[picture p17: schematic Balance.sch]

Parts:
C203: 1N; C_0805_2012Metric
D201: Green; LED_0805_2012Metric_Pad1.15x1.40mm_HandSolder
Q201: BC847; SOT-23
Q202: IRLML6244TRPBF; SOT-23
R201: 3K3; R_0805_2012Metric_Pad1.20x1.40mm_HandSolder
R202, R206: 47K; R_0805_2012Metric_Pad1.20x1.40mm_HandSolder
R203: 620; R_0805_2012Metric_Pad1.20x1.40mm_HandSolder
R204, R205: 1K; R_0805_2012Metric_Pad1.20x1.40mm_HandSolder
R207, R208, R209, R210: 10; R_2512_6332Metric_Pad1.40x3.35mm_HandSolder
R211: 91K; R_0805_2012Metric_Pad1.20x1.40mm_HandSolder
R212: 6K8; R_0805_2012Metric_Pad1.20x1.40mm_HandSolder
U201: PC817; SMDIP-4_W9.53mm_Clearance8mm

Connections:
/Cell1_bal: R201.2; also elsewhere on the board
/Vcell_1: R205.1, R207.1, R209.1, R211.1, U201.4; also elsewhere on the board
/Vcell_1_adc: C203.1, R211.2, R212.1; also elsewhere on the board
GND: C203.2, Q201.2 (E), Q202.2 (S), R202.2, R206.1, R212.2; also elsewhere on the board
unnamed: D201.1 (K), Q202.3 (D), R208.2, R210.2
unnamed: D201.2 (A), R205.2
unnamed: Q201.1 (B), R201.1, R202.1
unnamed: Q201.3 (C), U201.2
unnamed: Q202.1 (G), R204.1, R206.2
unnamed: R203.2, U201.1
unnamed: R204.2, U201.3
unnamed: R207.2, R208.1
unnamed: R209.2, R210.1
Vcell_2: R203.1; also elsewhere on the board

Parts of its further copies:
C303, C403, C503, C603, C703, C803, C903, C1003, C1103: 1N; C_0805_2012Metric
D301, D401, D501, D601, D701, D801, D901, D1001, D1101: Green; LED_0805_2012Metric_Pad1.15x1.40mm_HandSolder
Q301, Q401, Q501, Q601, Q701, Q801, Q901, Q1001, Q1101: BC847; SOT-23
Q302, Q402, Q502, Q602, Q702, Q802, Q902, Q1002, Q1102: IRLML6244TRPBF; SOT-23
R301, R401, R501, R601, R701, R801, R901, R1001, R1101: 3K3; R_0805_2012Metric_Pad1.20x1.40mm_HandSolder
R302, R306, R402, R406, R502, R506, R602, R606, R702, R706, R802, R806, R902, R906, R1002, R1006, R1102, R1106: 47K; R_0805_2012Metric_Pad1.20x1.40mm_HandSolder
R303, R403, R503, R603, R703, R803, R903, R1003, R1103: 620; R_0805_2012Metric_Pad1.20x1.40mm_HandSolder
R304, R305, R404, R405, R504, R505, R604, R605, R704, R705, R804, R805, R904, R905, R1004, R1005, R1104, R1105: 1K; R_0805_2012Metric_Pad1.20x1.40mm_HandSolder
R307, R308, R309, R310, R407, R408, R409, R410, R507, R508, R509, R510, R607, R608, R609, R610, R707, R708, R709, R710, R807, R808, R809, R810, R907, R908, R909, R910, R1007, R1008, R1009, R1010, R1107, R1108, R1109, R1110: 10; R_2512_6332Metric_Pad1.40x3.35mm_HandSolder
R311, R411, R511, R611, R711, R811, R911, R1011, R1111: 91K; R_0805_2012Metric_Pad1.20x1.40mm_HandSolder
R312, R412, R512, R612, R712, R812, R912, R1012, R1112: 6K8; R_0805_2012Metric_Pad1.20x1.40mm_HandSolder
U301, U401, U501, U601, U701, U801, U901, U1001, U1101: PC817; SMDIP-4_W9.53mm_Clearance8mm

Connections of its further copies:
/Cell2_bal: R301.2; also elsewhere on the board
/Cell3_bal: R401.2; also elsewhere on the board
/Cell4_bal: R501.2; also elsewhere on the board
/Cell5_bal: R601.2; also elsewhere on the board
/Cell6_bal: R701.2; also elsewhere on the board
/Cell7_bal: R801.2; also elsewhere on the board
/Cell8_bal: R901.2; also elsewhere on the board
/Cell9_bal: R1001.2; also elsewhere on the board
/Cell10_bal: R1101.2; also elsewhere on the board
/Vcell_1: Q302.2 (S), R306.1; also elsewhere on the board
/Vcell_2_adc: C303.1, R311.2, R312.1; also elsewhere on the board
/Vcell_3: Q502.2 (S), R405.1, R407.1, R409.1, R411.1, R506.1, U401.4; also elsewhere on the board
/Vcell_3_adc: C403.1, R411.2, R412.1; also elsewhere on the board
/Vcell_4: Q602.2 (S), R505.1, R507.1, R509.1, R511.1, R606.1, U501.4; also elsewhere on the board
/Vcell_4_adc: C503.1, R511.2, R512.1; also elsewhere on the board
/Vcell_5: Q702.2 (S), R605.1, R607.1, R609.1, R611.1, R706.1, U601.4; also elsewhere on the board
/Vcell_5_adc: C603.1, R611.2, R612.1; also elsewhere on the board
/Vcell_6: Q802.2 (S), R705.1, R707.1, R709.1, R711.1, R806.1, U701.4; also elsewhere on the board
/Vcell_6_adc: C703.1, R711.2, R712.1; also elsewhere on the board
/Vcell_7: Q902.2 (S), R805.1, R807.1, R809.1, R811.1, R906.1, U801.4; also elsewhere on the board
/Vcell_7_adc: C803.1, R811.2, R812.1; also elsewhere on the board
/Vcell_8: Q1002.2 (S), R905.1, R907.1, R909.1, R911.1, R1006.1, U901.4; also elsewhere on the board
/Vcell_8_adc: C903.1, R911.2, R912.1; also elsewhere on the board
/Vcell_9: Q1102.2 (S), R1005.1, R1007.1, R1009.1, R1011.1, R1106.1, U1001.4; also elsewhere on the board
/Vcell_9_adc: C1003.1, R1011.2, R1012.1; also elsewhere on the board
/Vcell_10: R1105.1, R1107.1, R1109.1, R1111.1, U1101.4; also elsewhere on the board
/Vcell_10_adc: C1103.1, R1111.2, R1112.1; also elsewhere on the board
GND: C303.2, C403.2, C503.2, C603.2, C703.2, C803.2, C903.2, C1003.2, C1103.2, Q301.2 (E), Q401.2 (E), Q501.2 (E), Q601.2 (E), Q701.2 (E), Q801.2 (E), Q901.2 (E), Q1001.2 (E), Q1101.2 (E), R302.2, R312.2, R402.2, R412.2, R502.2, R512.2, R602.2, R612.2, R702.2, R712.2, R802.2, R812.2, R902.2, R912.2, R1002.2, R1012.2, R1102.2, R1112.2; also elsewhere on the board
unnamed: D301.1 (K), Q302.3 (D), R308.2, R310.2
unnamed: D301.2 (A), R305.2
unnamed: D401.1 (K), Q402.3 (D), R408.2, R410.2
unnamed: D401.2 (A), R405.2
unnamed: D501.1 (K), Q502.3 (D), R508.2, R510.2
unnamed: D501.2 (A), R505.2
unnamed: D601.1 (K), Q602.3 (D), R608.2, R610.2
unnamed: D601.2 (A), R605.2
unnamed: D701.1 (K), Q702.3 (D), R708.2, R710.2
unnamed: D701.2 (A), R705.2
unnamed: D801.1 (K), Q802.3 (D), R808.2, R810.2
unnamed: D801.2 (A), R805.2
unnamed: D901.1 (K), Q902.3 (D), R908.2, R910.2
unnamed: D901.2 (A), R905.2
unnamed: D1001.1 (K), Q1002.3 (D), R1008.2, R1010.2
unnamed: D1001.2 (A), R1005.2
unnamed: D1101.1 (K), Q1102.3 (D), R1108.2, R1110.2
unnamed: D1101.2 (A), R1105.2
unnamed: Q301.1 (B), R301.1, R302.1
unnamed: Q301.3 (C), U301.2
unnamed: Q302.1 (G), R304.1, R306.2
unnamed: Q401.1 (B), R401.1, R402.1
unnamed: Q401.3 (C), U401.2
unnamed: Q402.1 (G), R404.1, R406.2
unnamed: Q501.1 (B), R501.1, R502.1
unnamed: Q501.3 (C), U501.2
unnamed: Q502.1 (G), R504.1, R506.2
unnamed: Q601.1 (B), R601.1, R602.1
unnamed: Q601.3 (C), U601.2
unnamed: Q602.1 (G), R604.1, R606.2
unnamed: Q701.1 (B), R701.1, R702.1
unnamed: Q701.3 (C), U701.2
unnamed: Q702.1 (G), R704.1, R706.2
unnamed: Q801.1 (B), R801.1, R802.1
unnamed: Q801.3 (C), U801.2
unnamed: Q802.1 (G), R804.1, R806.2
unnamed: Q901.1 (B), R901.1, R902.1
unnamed: Q901.3 (C), U901.2
unnamed: Q902.1 (G), R904.1, R906.2
unnamed: Q1001.1 (B), R1001.1, R1002.1
unnamed: Q1001.3 (C), U1001.2
unnamed: Q1002.1 (G), R1004.1, R1006.2
unnamed: Q1101.1 (B), R1101.1, R1102.1
unnamed: Q1101.3 (C), U1101.2
unnamed: Q1102.1 (G), R1104.1, R1106.2
unnamed: R303.2, U301.1
unnamed: R304.2, U301.3
unnamed: R307.2, R308.1
unnamed: R309.2, R310.1
unnamed: R403.2, U401.1
unnamed: R404.2, U401.3
unnamed: R407.2, R408.1
unnamed: R409.2, R410.1
unnamed: R503.2, U501.1
unnamed: R504.2, U501.3
unnamed: R507.2, R508.1
unnamed: R509.2, R510.1
unnamed: R603.2, U601.1
unnamed: R604.2, U601.3
unnamed: R607.2, R608.1
unnamed: R609.2, R610.1
unnamed: R703.2, U701.1
unnamed: R704.2, U701.3
unnamed: R707.2, R708.1
unnamed: R709.2, R710.1
unnamed: R803.2, U801.1
unnamed: R804.2, U801.3
unnamed: R807.2, R808.1
unnamed: R809.2, R810.1
unnamed: R903.2, U901.1
unnamed: R904.2, U901.3
unnamed: R907.2, R908.1
unnamed: R909.2, R910.1
unnamed: R1003.2, U1001.1
unnamed: R1004.2, U1001.3
unnamed: R1007.2, R1008.1
unnamed: R1009.2, R1010.1
unnamed: R1103.2, U1101.1
unnamed: R1104.2, U1101.3
unnamed: R1107.2, R1108.1
unnamed: R1109.2, R1110.1
Vcell_2: Q402.2 (S), R303.1, R305.1, R307.1, R309.1, R311.1, R403.1, R406.1, R503.1, R603.1, R703.1, R803.1, R903.1, R1003.1, R1103.1, U301.4; also elsewhere on the board

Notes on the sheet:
Calculation PC817 Led resistor If=10mA Vf=1.2V Vcell2 = 6-8.4 R=U/I=(7.2-1.2)/0.01=600=620 Imin = Umin/R=(6-1.2)/620=7.7mA Imax = Umin/R=(8.4-1.2)/620=11.6mA Prmax=I^2*R=0.0116^2*660=0.0888=88.8mW<125mW
Bleed Resistor Calculation Desired Bleed Current=0.5A average Rtot= U/I=3.6/0.5=7.2 ohm Pmax=Vmax^2/R=4.2^2/7.2=2.45W Rtot=(R1*R2)/(R1+R2) R1=R2 Rsingle is also 7.2 Psingle = 2.45/4=0.61W
Left away capacitor 1N base-gnd both transisor and mosfet to save components.
Base Resistor BC847 (Hfe of 200, Very worst case 100) First 1K, but the nRF can only handle max. 15mA Little bit border, set it to 10mA, leds have already some mA so, 7.5mA Measured 0.74v over BE R=2.56/0.00075=3.41k=3K3 200x0.00075=0.150mA, needed around 10 So plenty overhead, resistor could also 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
Max 42V 42 = 6.8/97.8 = 2.92 14 bits ADC Reference = Gain / Reference = 0.2 / 0.6 Volt = (adc value / 2^14) * 3

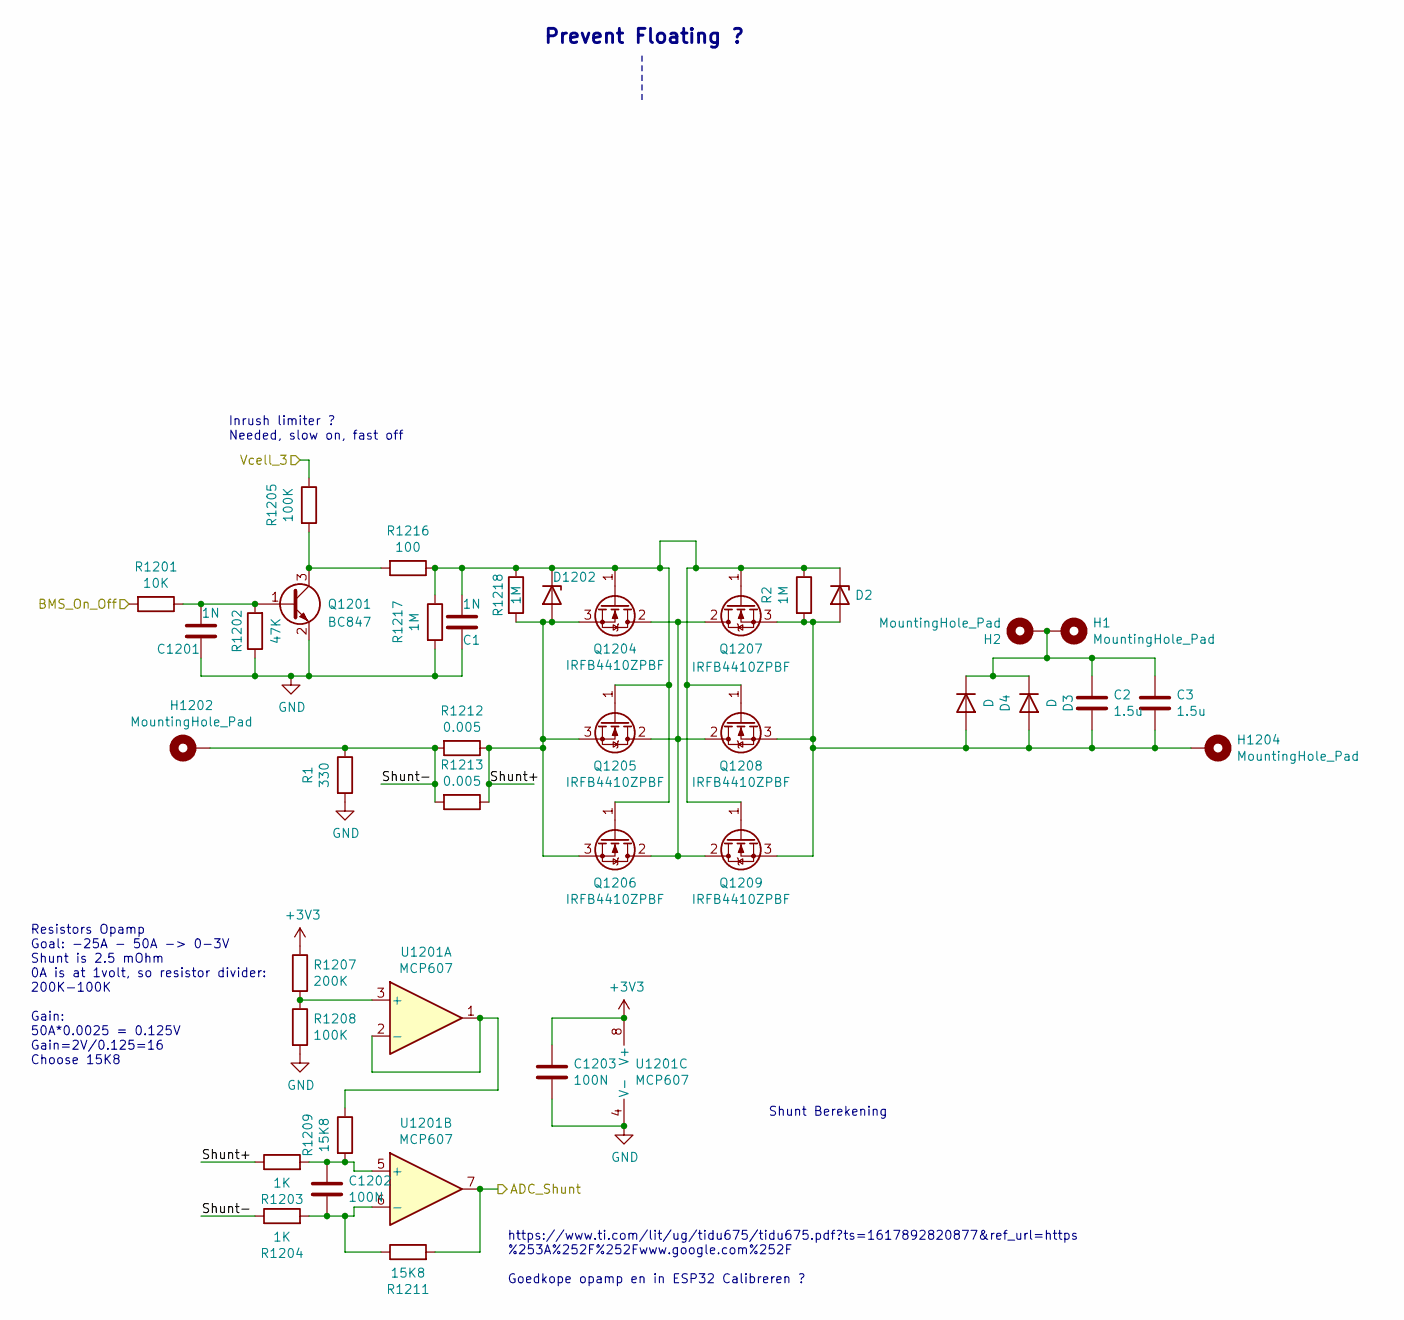
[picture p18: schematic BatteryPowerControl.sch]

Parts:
C1, C1201: 1N; C_0805_2012Metric_Pad1.18x1.45mm_HandSolder
C2, C3: 1.5u; C_1210_3225Metric_Pad1.33x2.70mm_HandSolder
C1202, C1203: 100N; C_0805_2012Metric
D2, D1202: Z1SMA15; D_SOD-523
D3, D4: D; D_SMA_Handsoldering
H1, H2, H1202, H1204: MountingHole_Pad; MountingHole_3.2mm_M3_ISO7380_Pad_TopBottom
Q1201: BC847; SOT-23
Q1204, Q1205, Q1206, Q1207, Q1208, Q1209: IRFB4410ZPBF; TO-220-3_Horizontal_TabDown_modified
R1: 330; R_0805_2012Metric_Pad1.20x1.40mm_HandSolder
R2, R1217, R1218: 1M; R_0805_2012Metric_Pad1.20x1.40mm_HandSolder
R1201: 10K; R_0805_2012Metric_Pad1.20x1.40mm_HandSolder
R1202: 47K; R_0805_2012Metric_Pad1.20x1.40mm_HandSolder
R1203, R1204: 1K; R_0805_2012Metric_Pad1.20x1.40mm_HandSolder
R1205, R1208: 100K; R_0805_2012Metric_Pad1.20x1.40mm_HandSolder
R1207: 200K; R_0805_2012Metric_Pad1.20x1.40mm_HandSolder
R1209, R1211: 15K8; R_0805_2012Metric_Pad1.20x1.40mm_HandSolder
R1212, R1213: 0.005; R_2512_6332Metric_Pad1.40x3.35mm_HandSolder
R1216: 100; R_0805_2012Metric_Pad1.20x1.40mm_HandSolder
U1201: MCP607; SOIC-8_3.9x4.9mm_P1.27mm

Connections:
+3V3: C1203.1, R1207.1, U1201.8 (V+); also elsewhere on the board
/BatteryPowerControl/BMS_On_Off: R1201.2; also elsewhere on the board
/BatteryPowerControl/Shunt+: D1202.2 (A), Q1204.3 (S), Q1205.3 (S), Q1206.3 (S), R1203.1, R1212.1, R1213.1, R1218.2
/BatteryPowerControl/Shunt-: H1202.1, R1.1, R1204.1, R1212.2, R1213.2
/MicrocontrollerNRF52/ADCShunt: R1211.2, U1201.7; also elsewhere on the board
/Vcell_3: R1205.1; also elsewhere on the board
GND: C1.2, C1201.2, C1203.2, Q1201.2 (E), R1.2, R1202.1, R1208.2, R1217.2, U1201.4 (V-); also elsewhere on the board
unnamed: C1.1, D2.1 (K), D1202.1 (K), Q1204.1 (G), Q1205.1 (G), Q1206.1 (G), Q1207.1 (G), Q1208.1 (G), Q1209.1 (G), R2.1, R1216.1, R1217.1, R1218.1
unnamed: C2.1, C3.1, D3.1 (K), D4.1 (K), H1.1, H2.1
unnamed: C2.2, C3.2, D2.2 (A), D3.2 (A), D4.2 (A), H1204.1, Q1207.3 (S), Q1208.3 (S), Q1209.3 (S), R2.2
unnamed: C1201.1, Q1201.1 (B), R1201.1, R1202.2
unnamed: C1202.1, R1203.2, R1209.2, U1201.5 (+)
unnamed: C1202.2, R1204.2, R1211.1, U1201.6 (-)
unnamed: Q1201.3 (C), R1205.2, R1216.2
unnamed: Q1204.2 (D), Q1205.2 (D), Q1206.2 (D), Q1207.2 (D), Q1208.2 (D), Q1209.2 (D)
unnamed: R1207.2, R1208.1, U1201.3 (+)
unnamed: R1209.1, U1201.1, U1201.2 (-)

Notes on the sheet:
https://www.ti.com/lit/ug/tidu675/tidu675.pdf?ts=1617892820877&ref_url=https %253A%252F%252Fwww.google.com%252F Goedkope opamp en in ESP32 Calibreren ?
Inrush limiter ? Needed, slow on, fast off
Prevent Floating ?
Shunt Berekening
Resistors Opamp Goal: -25A - 50A -> 0-3V Shunt is 2.5 mOhm 0A is at 1volt, so resistor divider: 200K-100K Gain: 50A*0.0025 = 0.125V Gain=2V/0.125=16 Choose 15K8

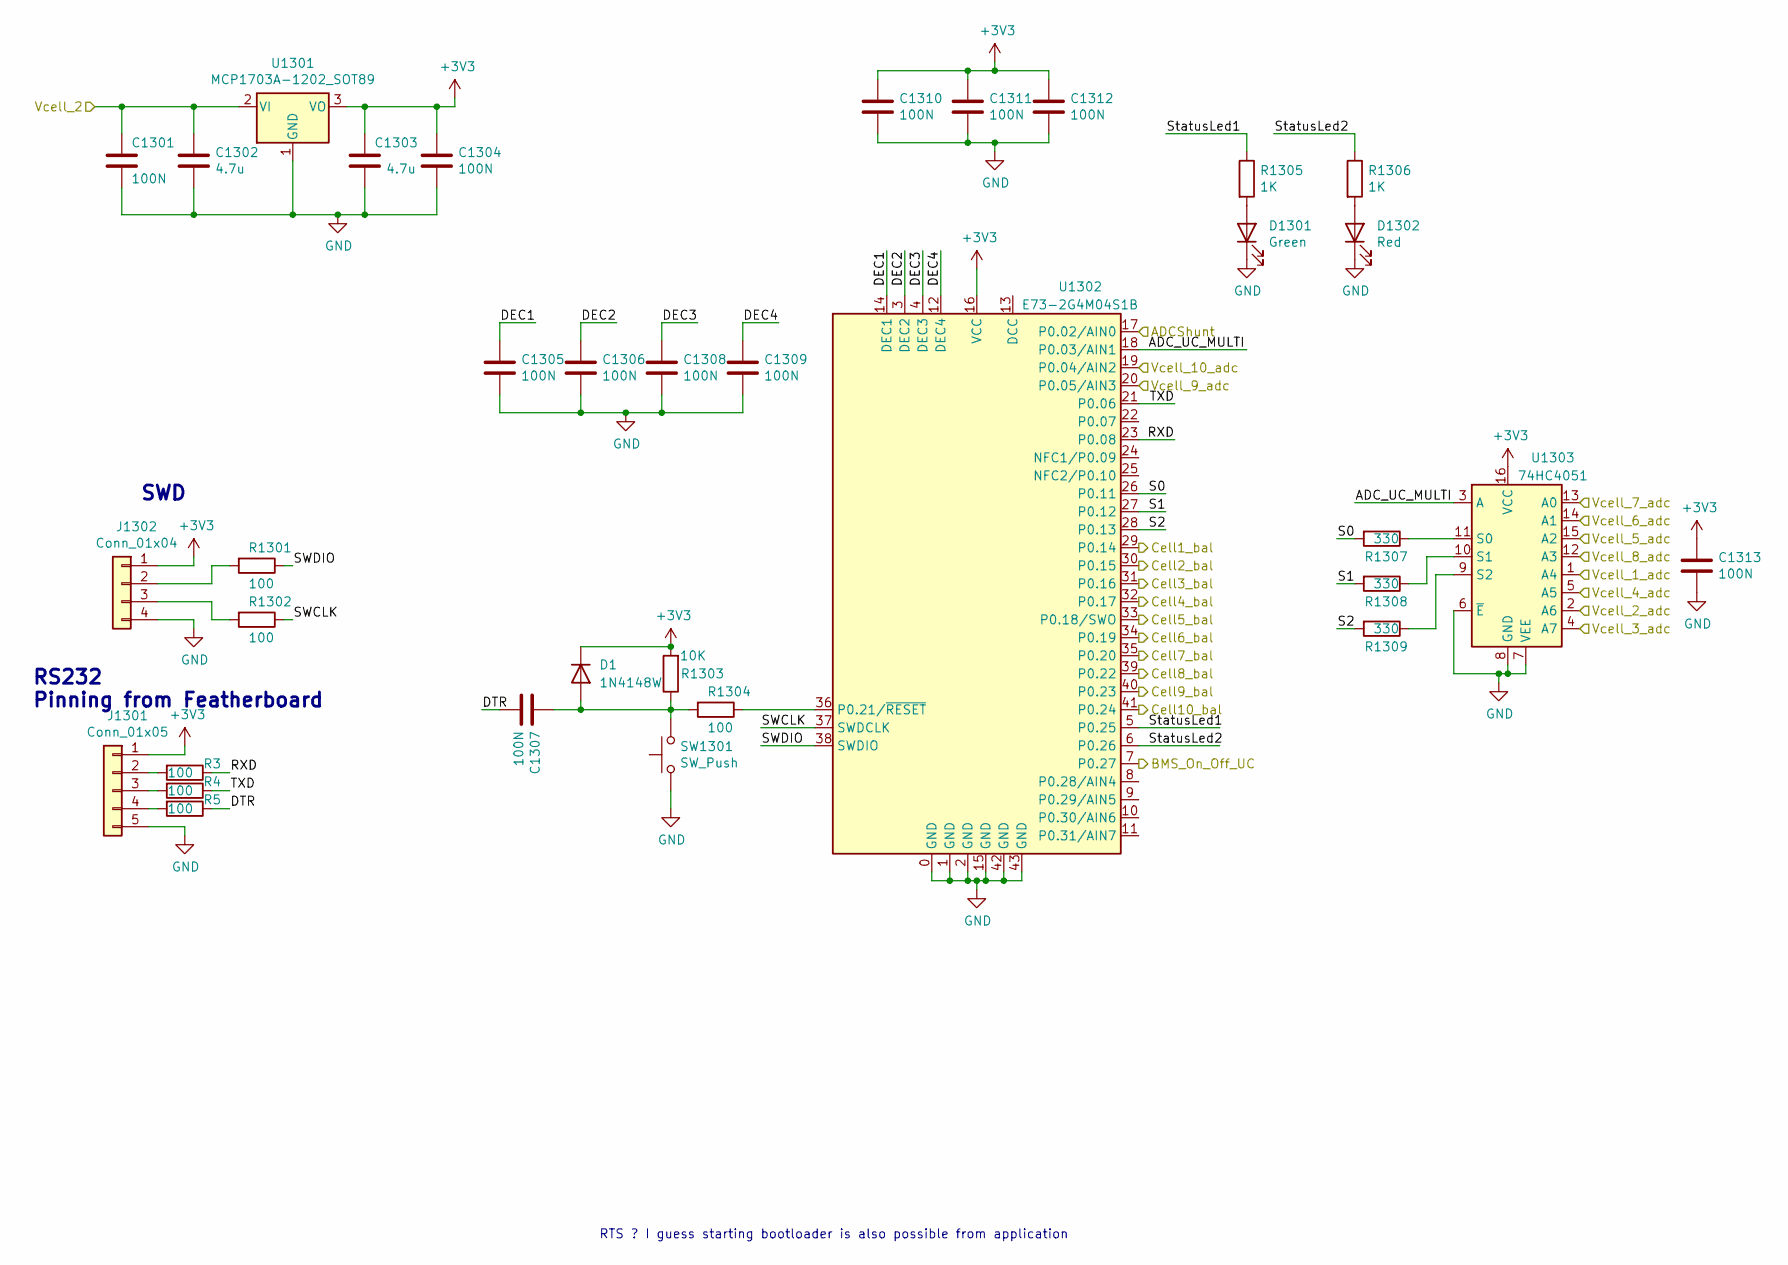
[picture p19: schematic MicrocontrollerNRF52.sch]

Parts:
C1301, C1304, C1305, C1306, C1307, C1308, C1309, C1310, C1311, C1312, C1313: 100N; C_0805_2012Metric
C1302, C1303: 4.7u; C_1210_3225Metric_Pad1.33x2.70mm_HandSolder
D1: 1N4148W; D_SOD-123
D1301: Green; LED_0805_2012Metric_Pad1.15x1.40mm_HandSolder
D1302: Red; LED_0805_2012Metric_Pad1.15x1.40mm_HandSolder
J1301: Conn_01x05; JST_PH_B5B-PH-K_1x05_P2.00mm_Vertical
J1302: Conn_01x04; JST_PH_B4B-PH-K_1x04_P2.00mm_Vertical
R3, R4, R5, R1301, R1302, R1304: 100; R_0805_2012Metric_Pad1.20x1.40mm_HandSolder
R1303: 10K; R_0805_2012Metric_Pad1.20x1.40mm_HandSolder
R1305, R1306: 1K; R_0805_2012Metric_Pad1.20x1.40mm_HandSolder
R1307, R1308, R1309: 330; R_0805_2012Metric_Pad1.20x1.40mm_HandSolder
SW1301: SW_Push; SW_Push_1P1T_NO_6x6mm_H9.5mm
U1301: MCP1703A-1202_SOT89; SOT-89-3
U1302: E73-2G4M04S1B
U1303: 74HC4051; SO-16_3.9x9.9mm_P1.27mm

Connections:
+3V3: C1303.1, C1304.1, C1310.1, C1311.1, C1312.1, C1313.1, D1.1 (K), J1301.1, J1302.1, R1303.2, U1301.3 (VO), U1302.16 (VCC), U1303.16 (VCC); also elsewhere on the board
/BatteryPowerControl/BMS_On_Off: U1302.7 (P0.27); also elsewhere on the board
/Cell1_bal: U1302.29 (P0.14); also elsewhere on the board
/Cell2_bal: U1302.30 (P0.15); also elsewhere on the board
/Cell3_bal: U1302.31 (P0.16); also elsewhere on the board
/Cell4_bal: U1302.32 (P0.17); also elsewhere on the board
/Cell5_bal: U1302.33 (P0.18/SWO); also elsewhere on the board
/Cell6_bal: U1302.34 (P0.19); also elsewhere on the board
/Cell7_bal: U1302.35 (P0.20); also elsewhere on the board
/Cell8_bal: U1302.39 (P0.22); also elsewhere on the board
/Cell9_bal: U1302.40 (P0.23); also elsewhere on the board
/Cell10_bal: U1302.41 (P0.24); also elsewhere on the board
/MicrocontrollerNRF52/ADCShunt: U1302.17 (P0.02/AIN0); also elsewhere on the board
/MicrocontrollerNRF52/ADC_UC_MULTI: U1302.18 (P0.03/AIN1), U1303.3 (A)
/MicrocontrollerNRF52/DEC1: C1305.1, U1302.14 (DEC1)
/MicrocontrollerNRF52/DEC2: C1306.1, U1302.3 (DEC2)
/MicrocontrollerNRF52/DEC3: C1308.1, U1302.4 (DEC3)
/MicrocontrollerNRF52/DEC4: C1309.1, U1302.12 (DEC4)
/MicrocontrollerNRF52/DTR: C1307.2, R5.1
/MicrocontrollerNRF52/RXD: R3.1, U1302.23 (P0.08)
/MicrocontrollerNRF52/S0: R1307.2, U1302.26 (P0.11)
/MicrocontrollerNRF52/S1: R1308.2, U1302.27 (P0.12)
/MicrocontrollerNRF52/S2: R1309.2, U1302.28 (P0.13)
/MicrocontrollerNRF52/SWCLK: R1302.1, U1302.37 (SWDCLK)
/MicrocontrollerNRF52/SWDIO: R1301.1, U1302.38 (SWDIO)
/MicrocontrollerNRF52/StatusLed1: R1305.1, U1302.5 (P0.25)
/MicrocontrollerNRF52/StatusLed2: R1306.1, U1302.6 (P0.26)
/MicrocontrollerNRF52/TXD: R4.1, U1302.21 (P0.06)
/Vcell_1_adc: U1303.1 (A4); also elsewhere on the board
/Vcell_2_adc: U1303.2 (A6); also elsewhere on the board
/Vcell_3_adc: U1303.4 (A7); also elsewhere on the board
/Vcell_4_adc: U1303.5 (A5); also elsewhere on the board
/Vcell_5_adc: U1303.15 (A2); also elsewhere on the board
/Vcell_6_adc: U1303.14 (A1); also elsewhere on the board
/Vcell_7_adc: U1303.13 (A0); also elsewhere on the board
/Vcell_8_adc: U1303.12 (A3); also elsewhere on the board
/Vcell_9_adc: U1302.20 (P0.05/AIN3); also elsewhere on the board
/Vcell_10_adc: U1302.19 (P0.04/AIN2); also elsewhere on the board
GND: C1301.2, C1302.2, C1303.2, C1304.2, C1305.2, C1306.2, C1308.2, C1309.2, C1310.2, C1311.2, C1312.2, C1313.2, D1301.1 (K), D1302.1 (K), J1301.5, J1302.4, SW1301.1, U1301.1 (GND), U1302.0 (GND), U1302.1 (GND), U1302.2 (GND), U1302.15 (GND), U1302.42 (GND), U1302.43 (GND), U1303.6 (~E), U1303.7 (VEE), U1303.8 (GND); also elsewhere on the board
unnamed: C1307.1, D1.2 (A), R1303.1, R1304.2, SW1301.2
unnamed: D1301.2 (A), R1305.2
unnamed: D1302.2 (A), R1306.2
unnamed: J1301.2, R3.2
unnamed: J1301.3, R4.2
unnamed: J1301.4, R5.2
unnamed: J1302.2, R1301.2
unnamed: J1302.3, R1302.2
unnamed: R1304.1, U1302.36 (P0.21/~RESET)
unnamed: R1307.1, U1303.11 (S0)
unnamed: R1308.1, U1303.10 (S1)
unnamed: R1309.1, U1303.9 (S2)
Vcell_2: C1301.1, C1302.1, U1301.2 (VI); also elsewhere on the board

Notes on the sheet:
SWD
RS232 Pinning from Featherboard
RTS ? I guess starting bootloader is also possible from application

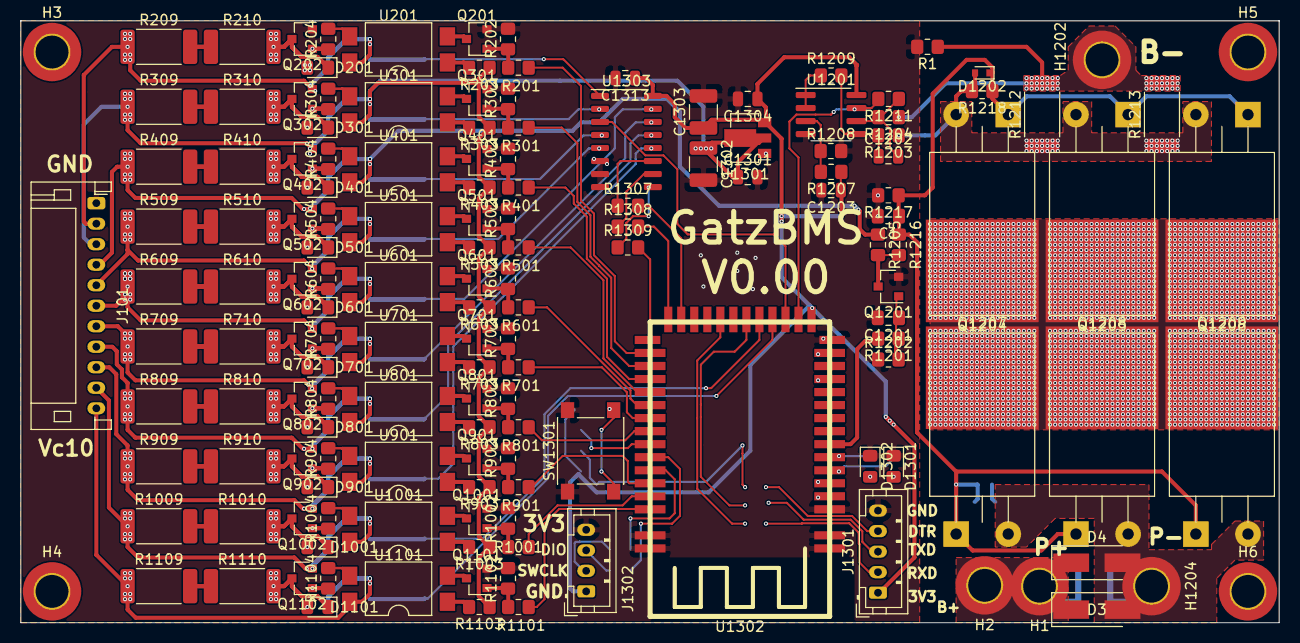
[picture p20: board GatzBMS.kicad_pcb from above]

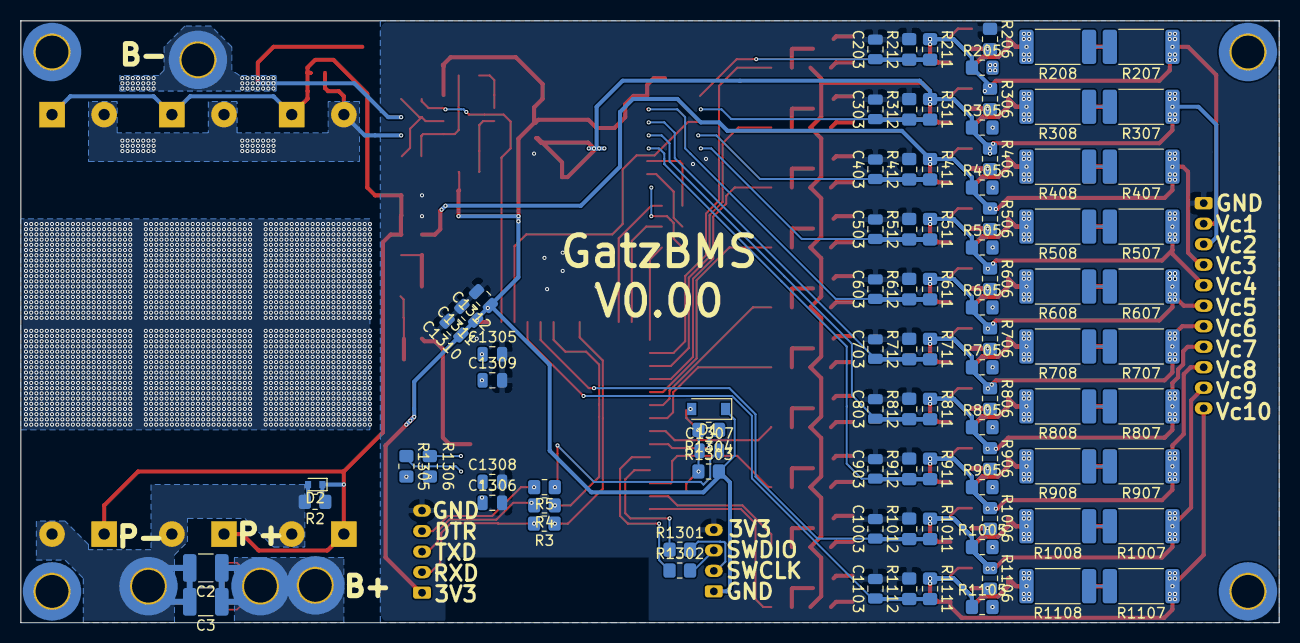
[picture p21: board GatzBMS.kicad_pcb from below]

Board: 2 copper layers, 122.7 x 58.7 mm, 247 parts (92 on the bottom side), 163 nets.
